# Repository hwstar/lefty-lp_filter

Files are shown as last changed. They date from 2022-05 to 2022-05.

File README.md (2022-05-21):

# Lefty-lp_filter
Lefty 8 Band Low Pass filter board

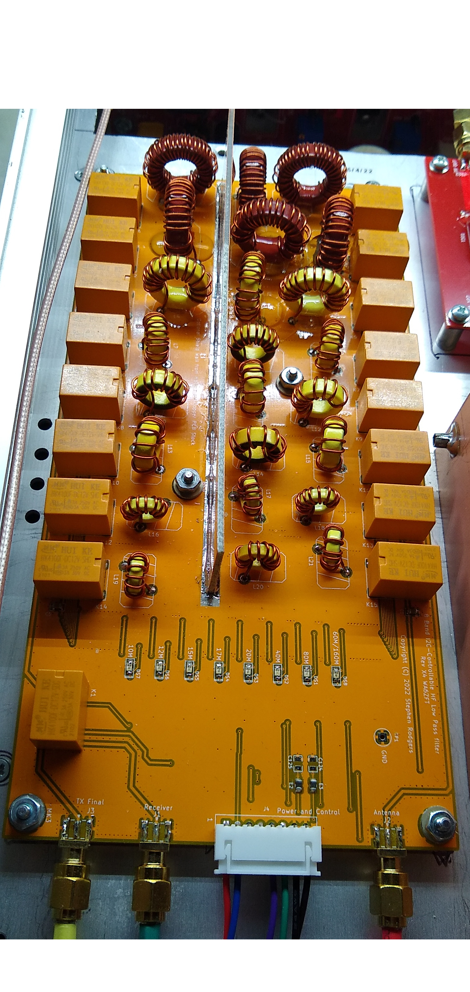
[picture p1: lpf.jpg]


This is an 8 band low pass filter board for the Lefty Transceiver.

The schematic capture and pwb layout was originally done in KiCAD 5 and migrated to KiCAD 6.

The filters are individually selectable via an I2C port expander.

The filter topology used in the design is:

"Second-Harmonic Optimized Low Pass Filters" by Ed Wetherhold, W3NQN
https://www.arrl.org/files/file/Technology/tis/info/pdf/9902044.pdf

The pdf schematic file is: lp_filter_8_bands.pdf

The BOM file is: lp_filter_8_bands_BOM.csv

The gerber files are in the directory LPF_X4_FAB.

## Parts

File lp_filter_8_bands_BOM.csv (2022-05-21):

Item | Part Number | Qty | Reference(s) | Title/Description | Value on Schematic | Manufacturer | Manufacturer Part Number
1 | 800003-104 | 23 | C1,C4-C8,C107-C123 | CAP,0805,0.1u,25V,X5R | 0.1u | Open Market | N/A
2 | 800232-470 | 3 | C10,C36,C94 | CAP,0805,C0G,47PF,250V | 47p | Open Market | N/A
3 | 800232-222 | 2 | C98,C101 | CAP,0805,C0G,2200PF,250V | 2200p | Open Market | N/A
4 | 800232-331 | 11 | C24,C27,C28,C30,C31,C33,C40,C43,C93,C99,C102 | CAP,0805,C0G,330PF,250V | 330p | Open Market | N/A
5 | 800232-152 | 2 | C95,C104 | CAP,0805,C0G,1500PF,250V | 1500p | Open Market | N/A
6 | 800232-151 | 7 | C9,C53,C56,C63,C72,C96,C105 | CAP,0805,C0G,150PF,250V | 150p | Open Market | N/A
7 | 800232-471 | 2 | C11,C20 | CAP,0805,C0G,470PF,250V | 470p | Open Market | N/A
8 | 800232-391 | 2 | C12,C21 | CAP,0805,C0G,390PF,250V | 390p | Open Market | N/A
9 | 800239-101 | 2 | C124,C125 | CAP,0805,C0G/NPO,100PF,50V | 100p | Open Market | N/A
10 | 800232-122 | 2 | C14,C17 | CAP,0805,C0G,1200PF,250V | 1200p | Open Market | N/A
11 | 800232-101 | 9 | C15,C18,C23,C25,C34,C54,C57,C85,C91 | CAP,0805,C0G,100PF,250V | 100p | Open Market | N/A
12 | 800003-106 | 2 | C2,C3 | CAP,0805,10u,25V,X5R | 10u | Open Market | N/A
13 | 800232-221 | 4 | C37,C46,C66,C69 | CAP,0805,C0G,220PF,250V | 220p | Open Market | N/A
14 | 800232-390 | 1 | C49 | CAP,0805,C0G,39PF,250V | 39p | Open Market | N/A
15 | 800232-820 | 8 | C50,C51,C59,C60,C87-C90 | CAP,0805,C0G,82PF,250V | 82p | Open Market | N/A
16 | 800232-330 | 1 | C62 | CAP,0805,C0G,33PF,250V | 33p | Open Market | N/A
17 | 800232-270 | 2 | C75,C84 | CAP,0805,C0G,27PF,250V | 27p | Open Market | N/A
18 | 800232-121 | 2 | C76,C82 | CAP,0805,C0G,120PF,250V | 120p | Open Market | N/A
19 | 800232-181 | 2 | C78,C80 | CAP,0805,C0G,180PF,250V | 180p | Open Market | N/A
20 | 800127-101 | 9 | CR1-CR9 | DIODE,SCHOTTKY,SGL,SOT-23 | BAT54 | Diodes Inc. | BAT54-7-F
21 | 800113-102 | 8 | DS1-DS8 | LED,GREEN,0805 | GREEN | Open Market | N/A
22 | 800245-601 | 3 | E1-E3 | FERRITE,CHIP,0805,600 ohm,100MHz,500mA | FB0805 | Sunlord | GZ2012U601TF
23 | 800233-101 | 3 | J1-J3 | CONN,SOC,SMA,LAUNCH,0.062 PCB | CONN_SMA_LAUNCH | Kinghelm | KH-SMA-KE8-G
24 | 800114-108 | 1 | J4 | CONN,HDR,SHROUDED,8 CKT,5MM,XH SERIES | CONN8 | JST | B8B-XH-A
25 | 800231-101 | 17 | K1-K17 | RELAY,SPDT,12V,3A | HK4100F-DC12V-SHCG | HUIKE | HK4100F-DC12V-SHCG
26 | 800234-802 | 6 | L1-L3,L22-L24 | TOROID,POWDERED_IRON,T80-2 | 2.68uH | Open Market | T80-2
27 | 800234-506 | 15 | L7-L21 | TOROID,POWDERED_IRON,T50-6 | 0.67uH | Open Market | T50-6
28 | 800234-686 | 3 | L4-L6 | TOROID,POWDERED_IRON,T68-6 | 1.34uH | Open Market | T68-6
29 | 800110-101 | 8 | Q1-Q8 | XSTR,GP,NPN,40V,SOT23 | MMBT4401 | Fairchild Semiconductor | MMBT4401
30 | 800235-222 | 8 | R1,R3,R7,R9,R19,R21,R23,R25 | RES,0805,2.2K,1% | 2.2K | Open Market | N/A
31 | 800235-123 | 8 | R10-R17 | RES,0805,12K,1% | 12K | Open Market | N/A
32 | 800235-102 | 8 | R2,R4,R8,R18,R20,R22,R24,R26 | RES,0805,1.0K,1% | 1K | Open Market | N/A
33 | 800235-103 | 2 | R5,R6 | RES,0805,10K,1% | 10K | Open Market | N/A
34 | 800116-101 | 1 | TP1 | CONN,HDR,1CKT,0.1PITCH,BERGSTRIP | GND | Open Market | N/A
35 | 800237-101 | 1 | U1 | IC, I2C BUS EXPANDER, 8 BIT, TSSOP16 | PCA9554APW | NEXPERIA | PCA9554APW
36 | 800121-101 | 1 | VR1 | IC,VREG,3.3V,1A,SOT-223 | NCP1117ST33 | On Semiconductor | NCP1117ST33T3G
37 | XXXXXX-XXX | 38 | C100,C103,C106,C13,C16,C19,C22,C26,C29,C32,C35,C38,C39,C41,C42,C44,C45,C47,C48,C52,C55,C58,C61,C64,C65,C67,C68,C70,C71,C73,C74,C77,C79,C81,C83,C86,C92,C97 | DNI | DNI | DNI | DNI

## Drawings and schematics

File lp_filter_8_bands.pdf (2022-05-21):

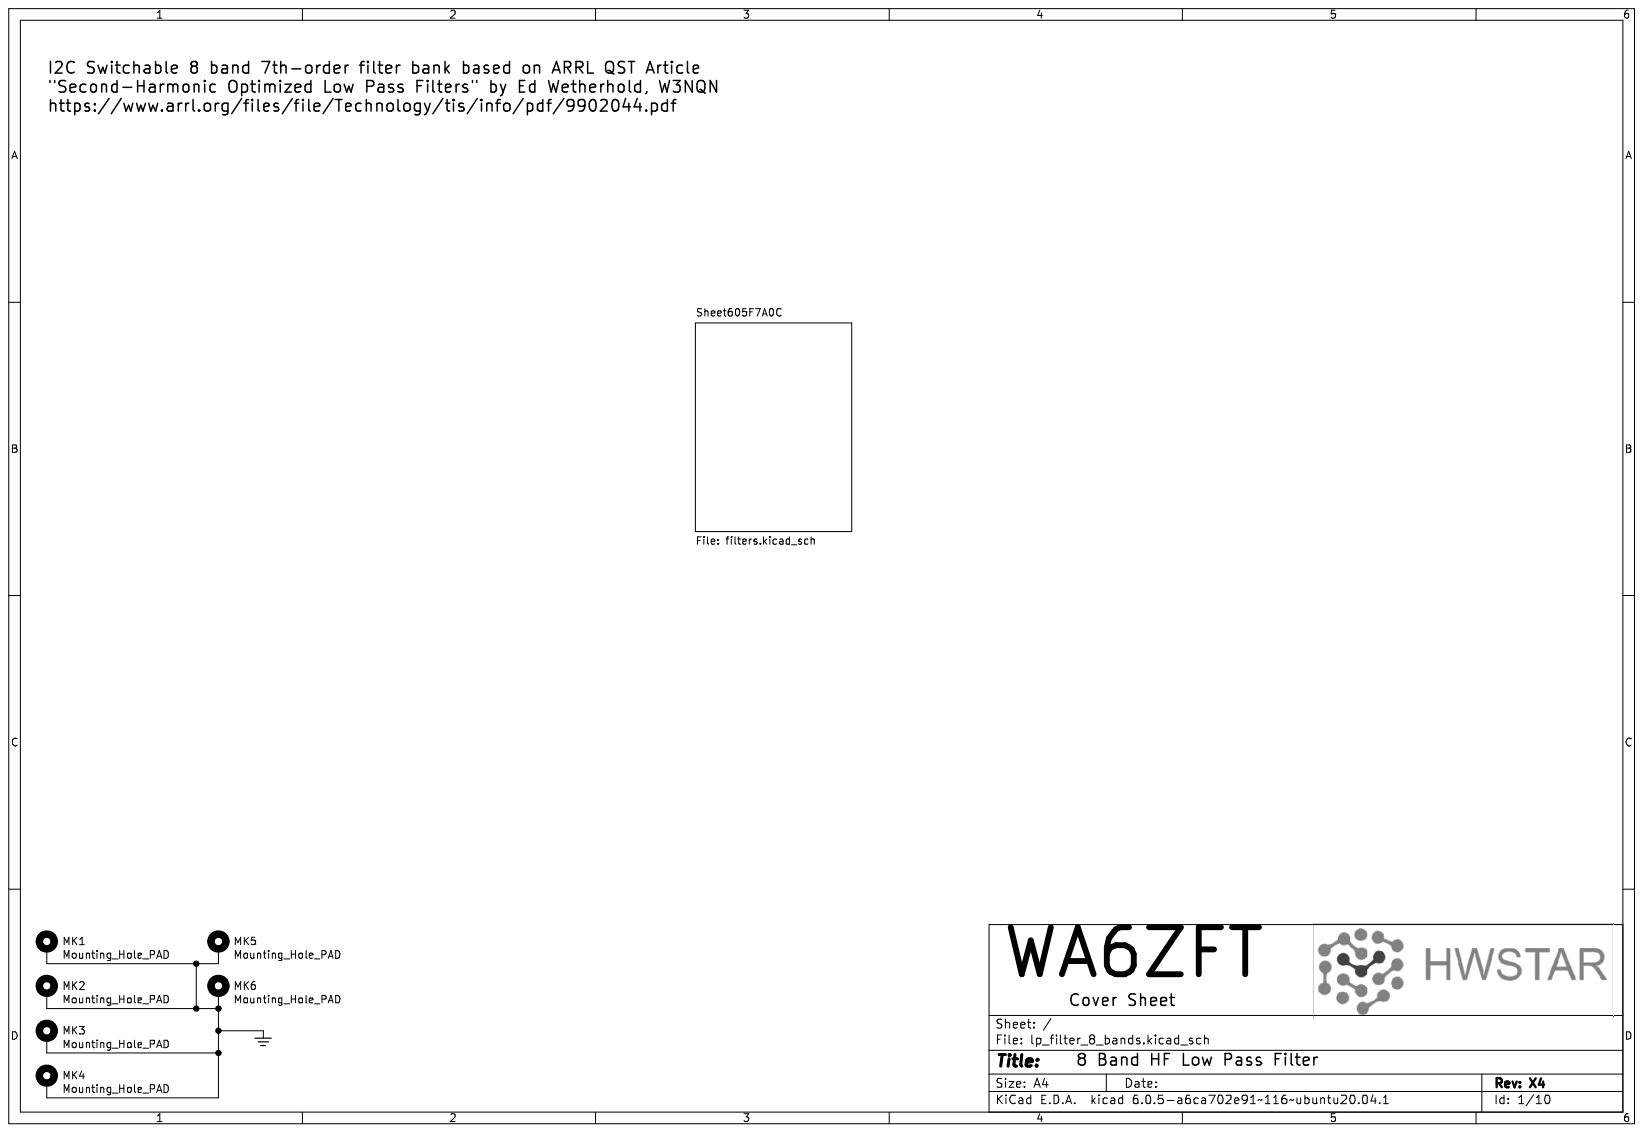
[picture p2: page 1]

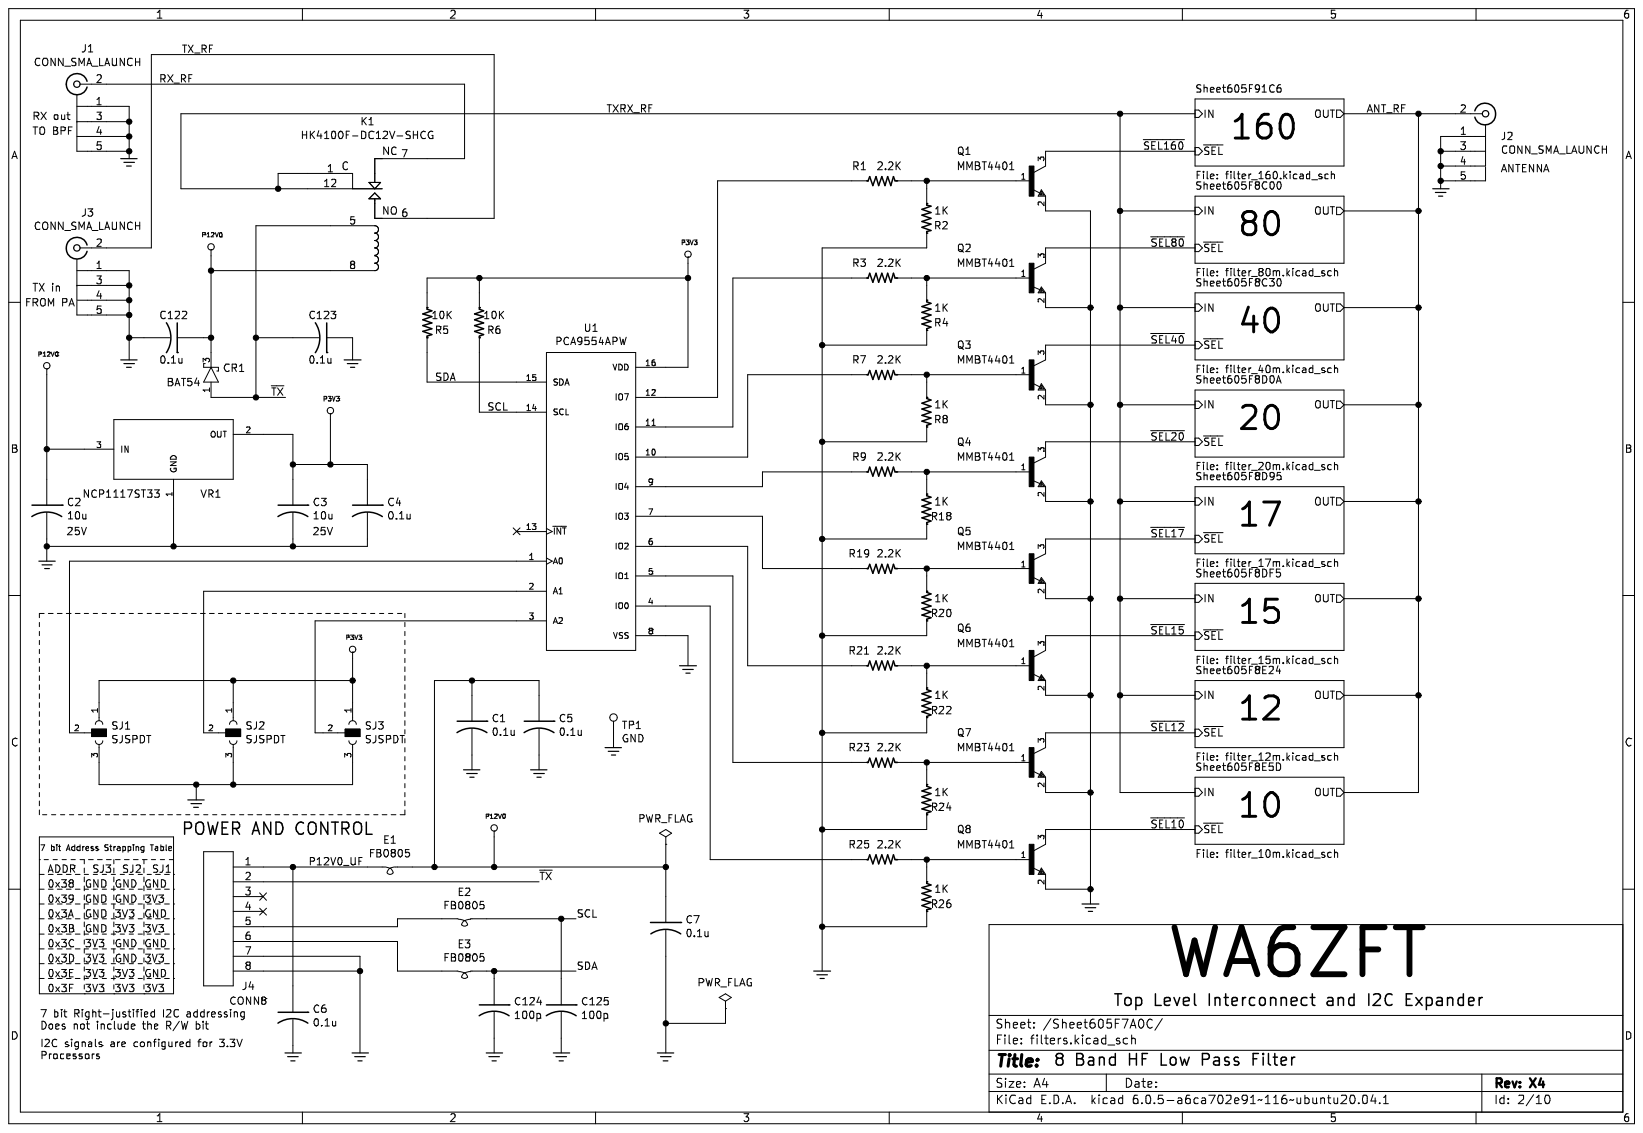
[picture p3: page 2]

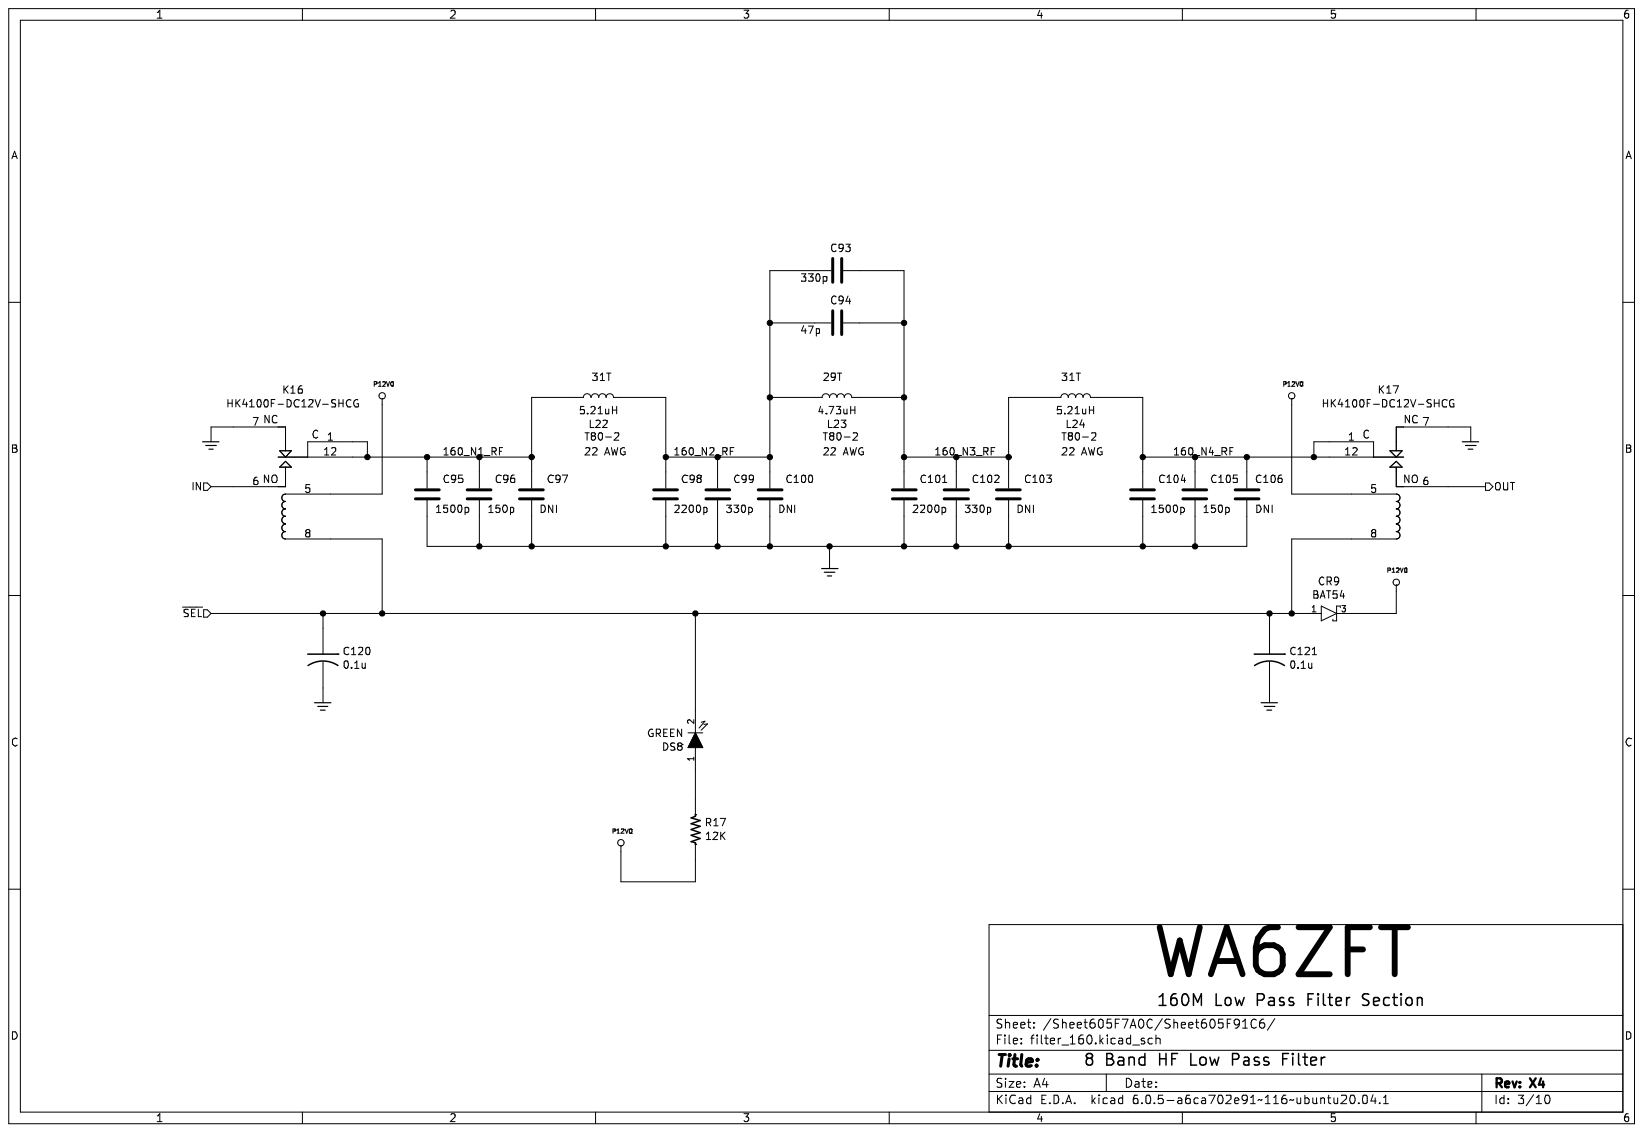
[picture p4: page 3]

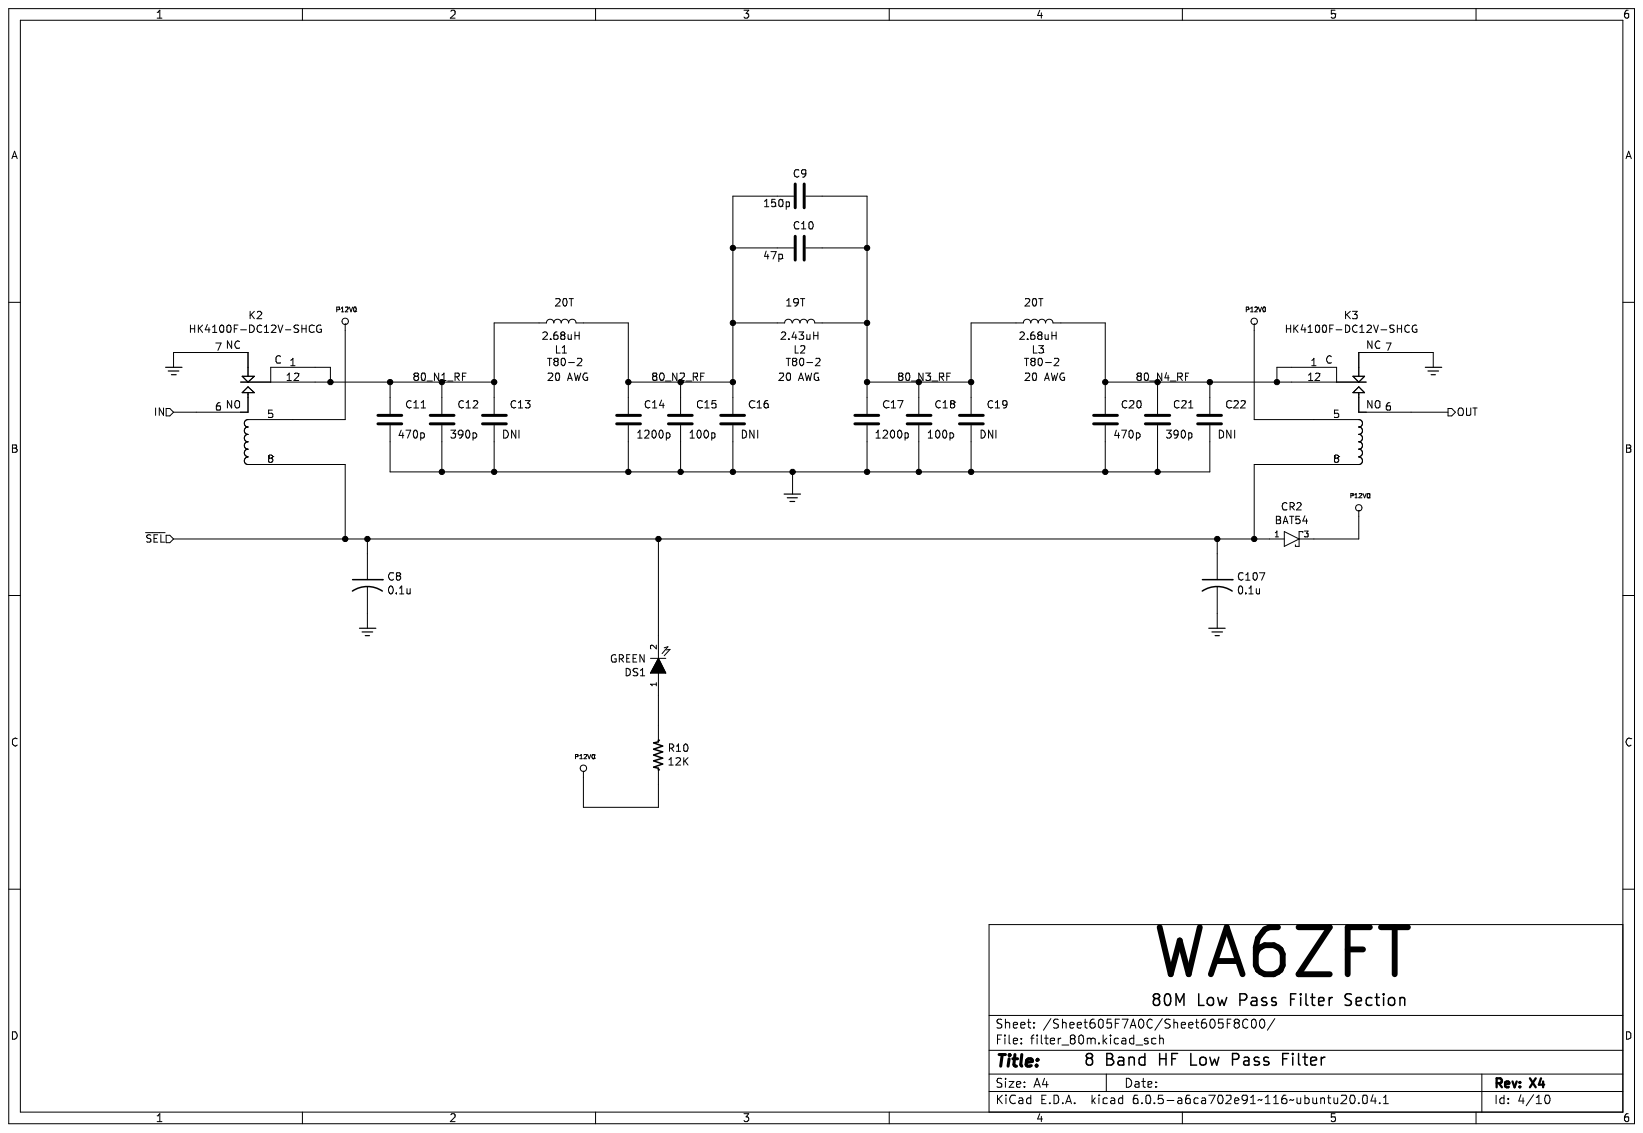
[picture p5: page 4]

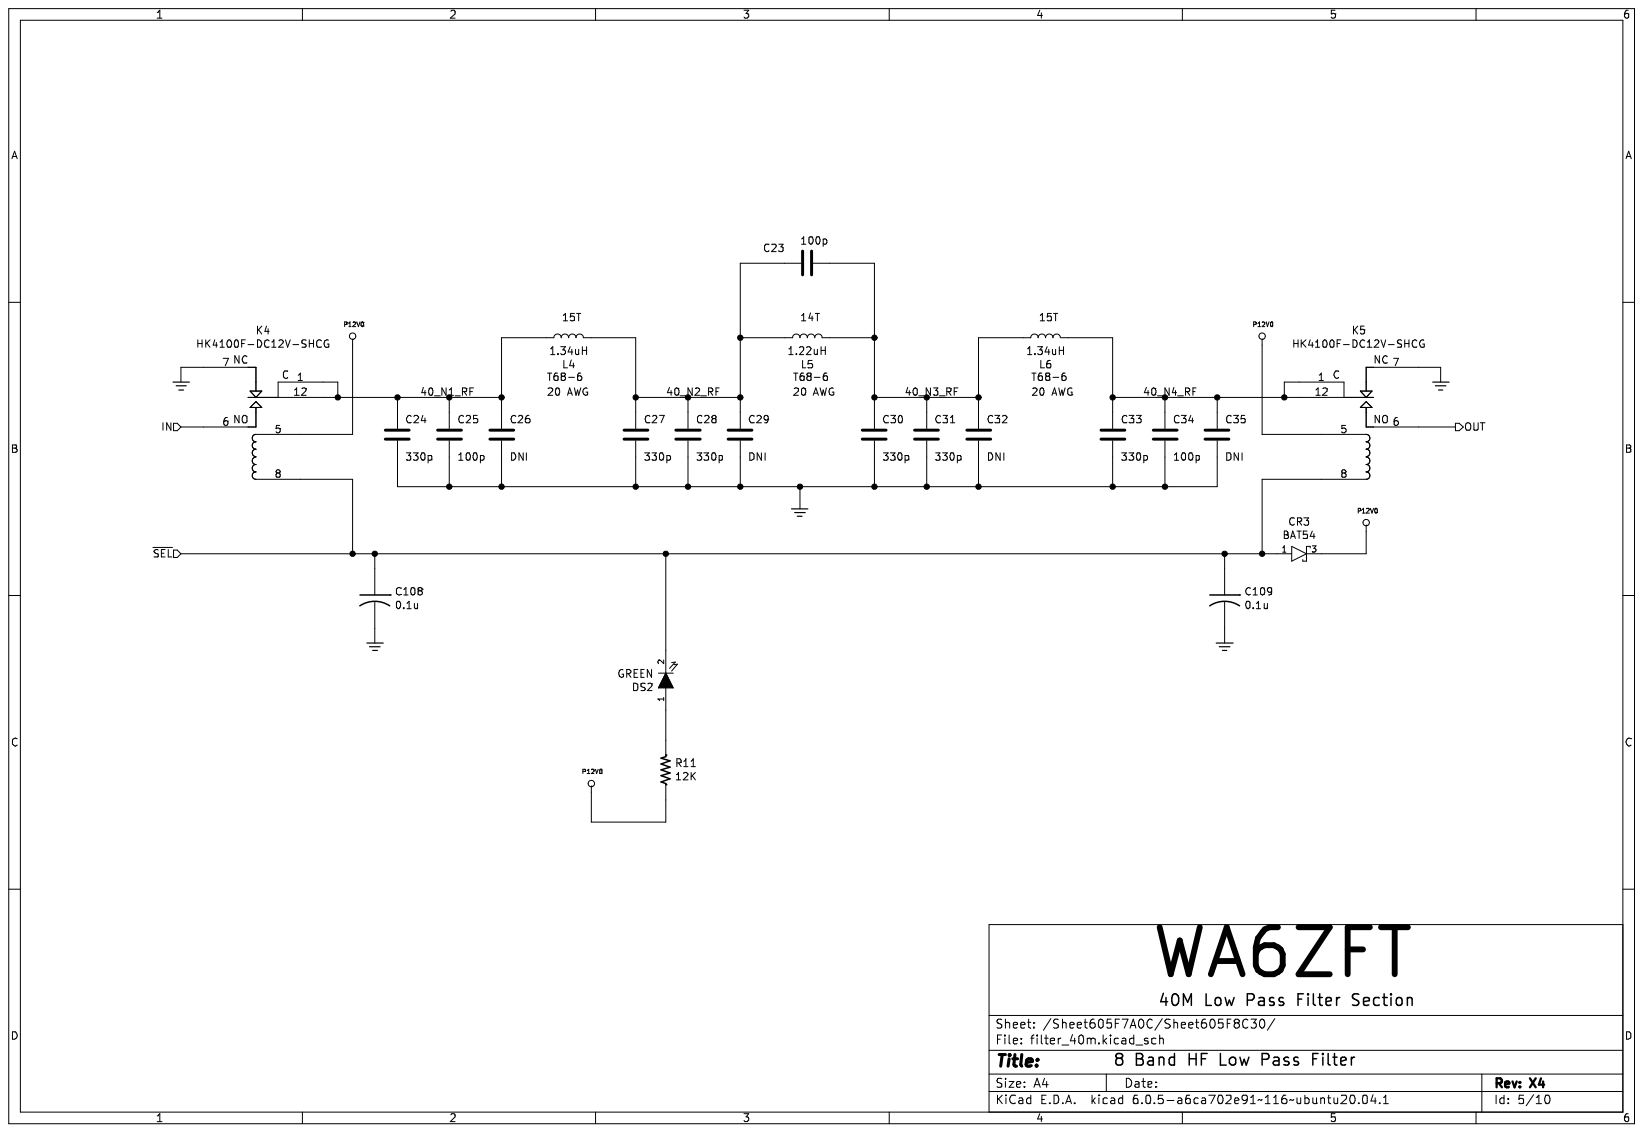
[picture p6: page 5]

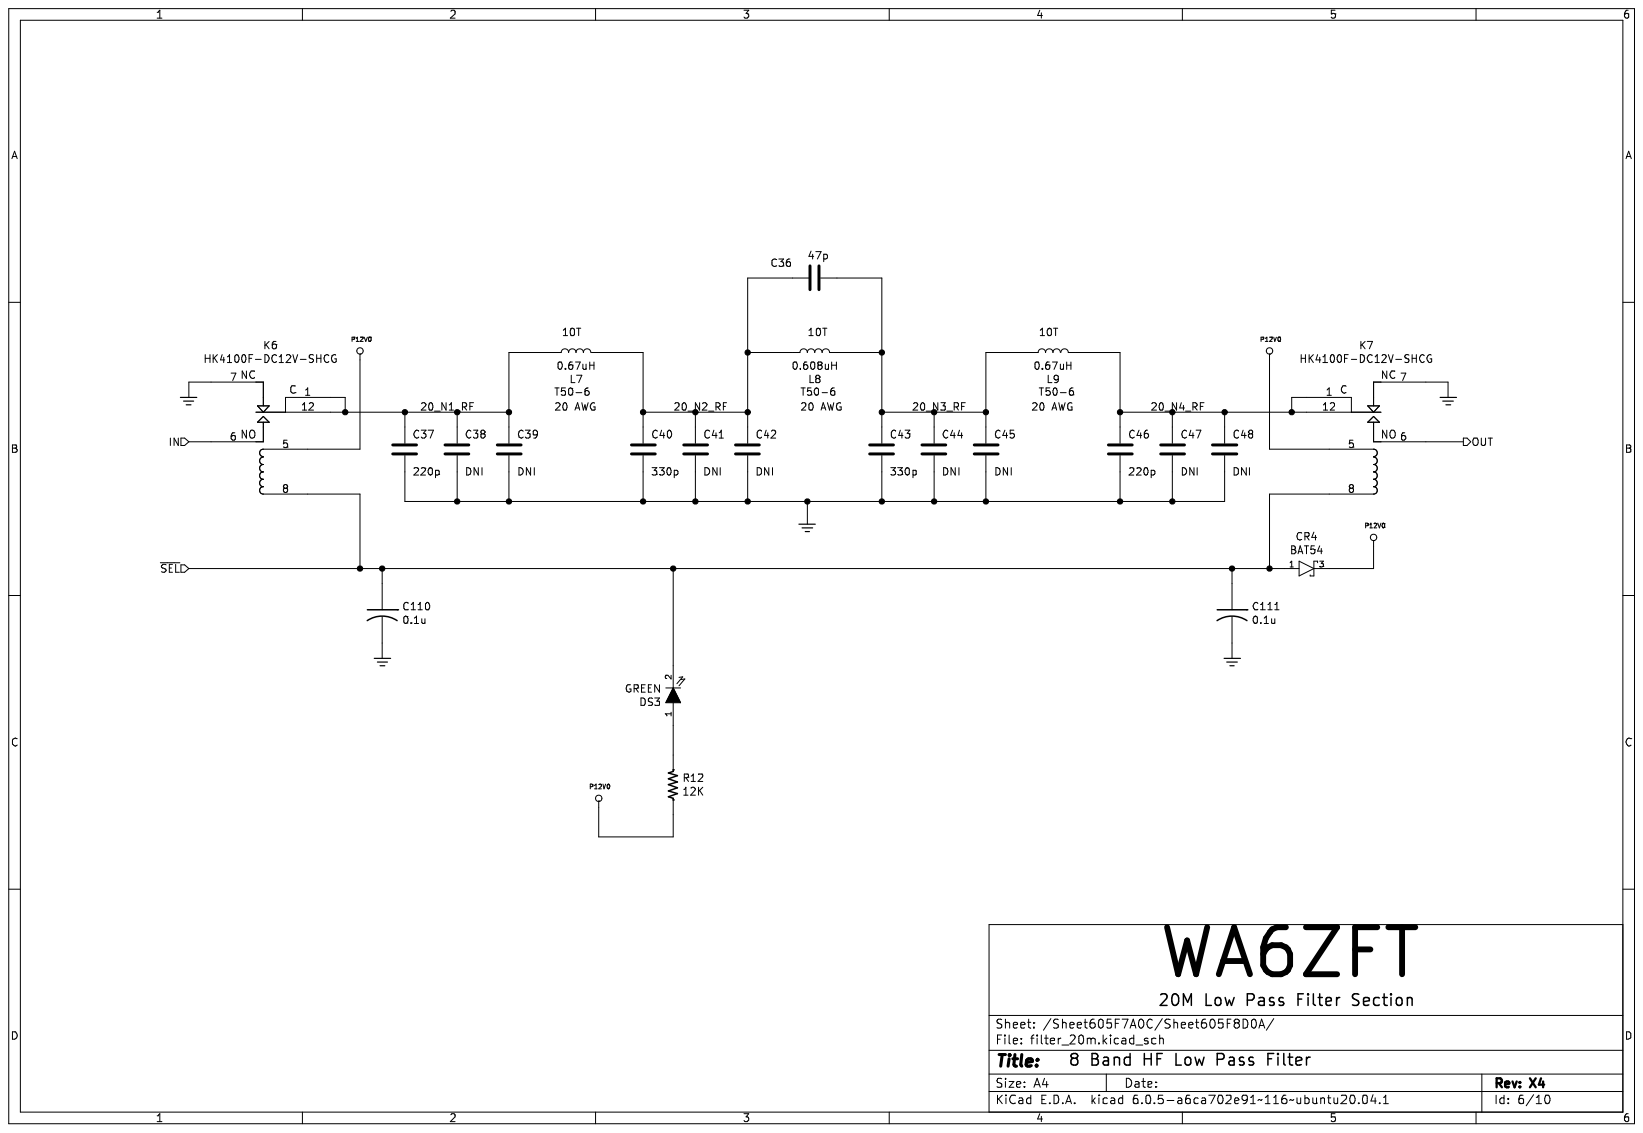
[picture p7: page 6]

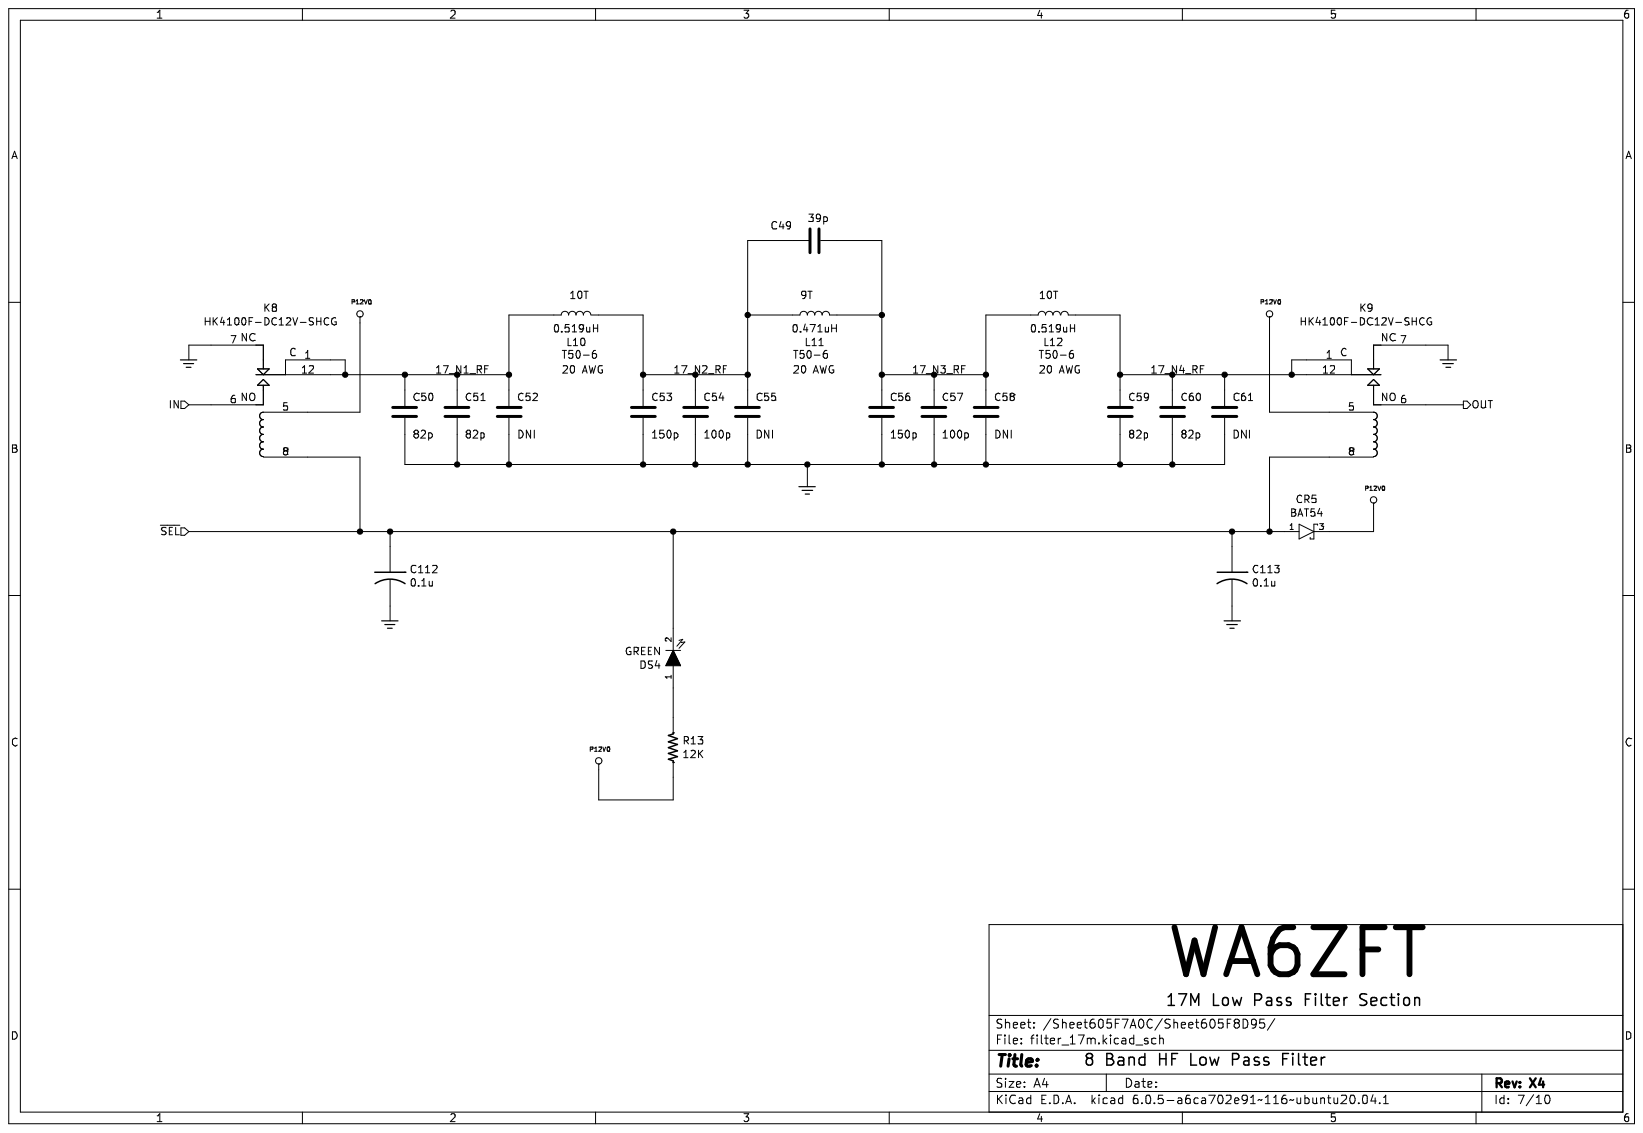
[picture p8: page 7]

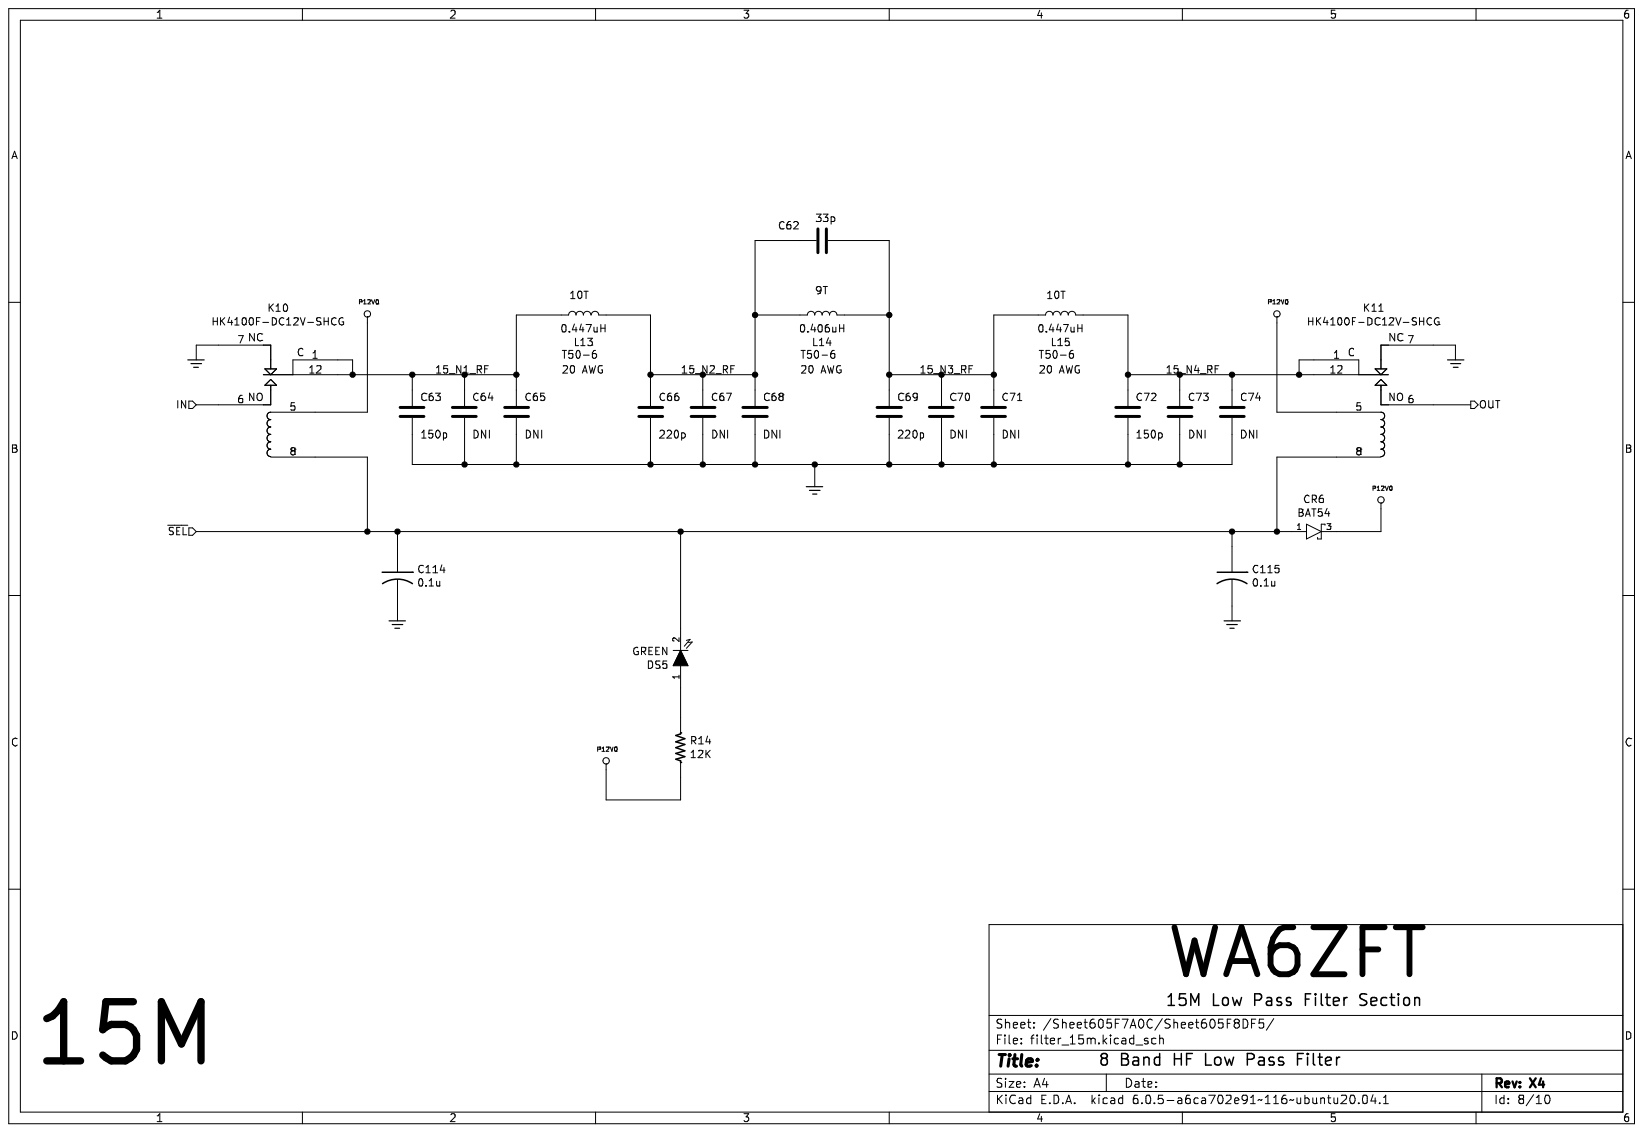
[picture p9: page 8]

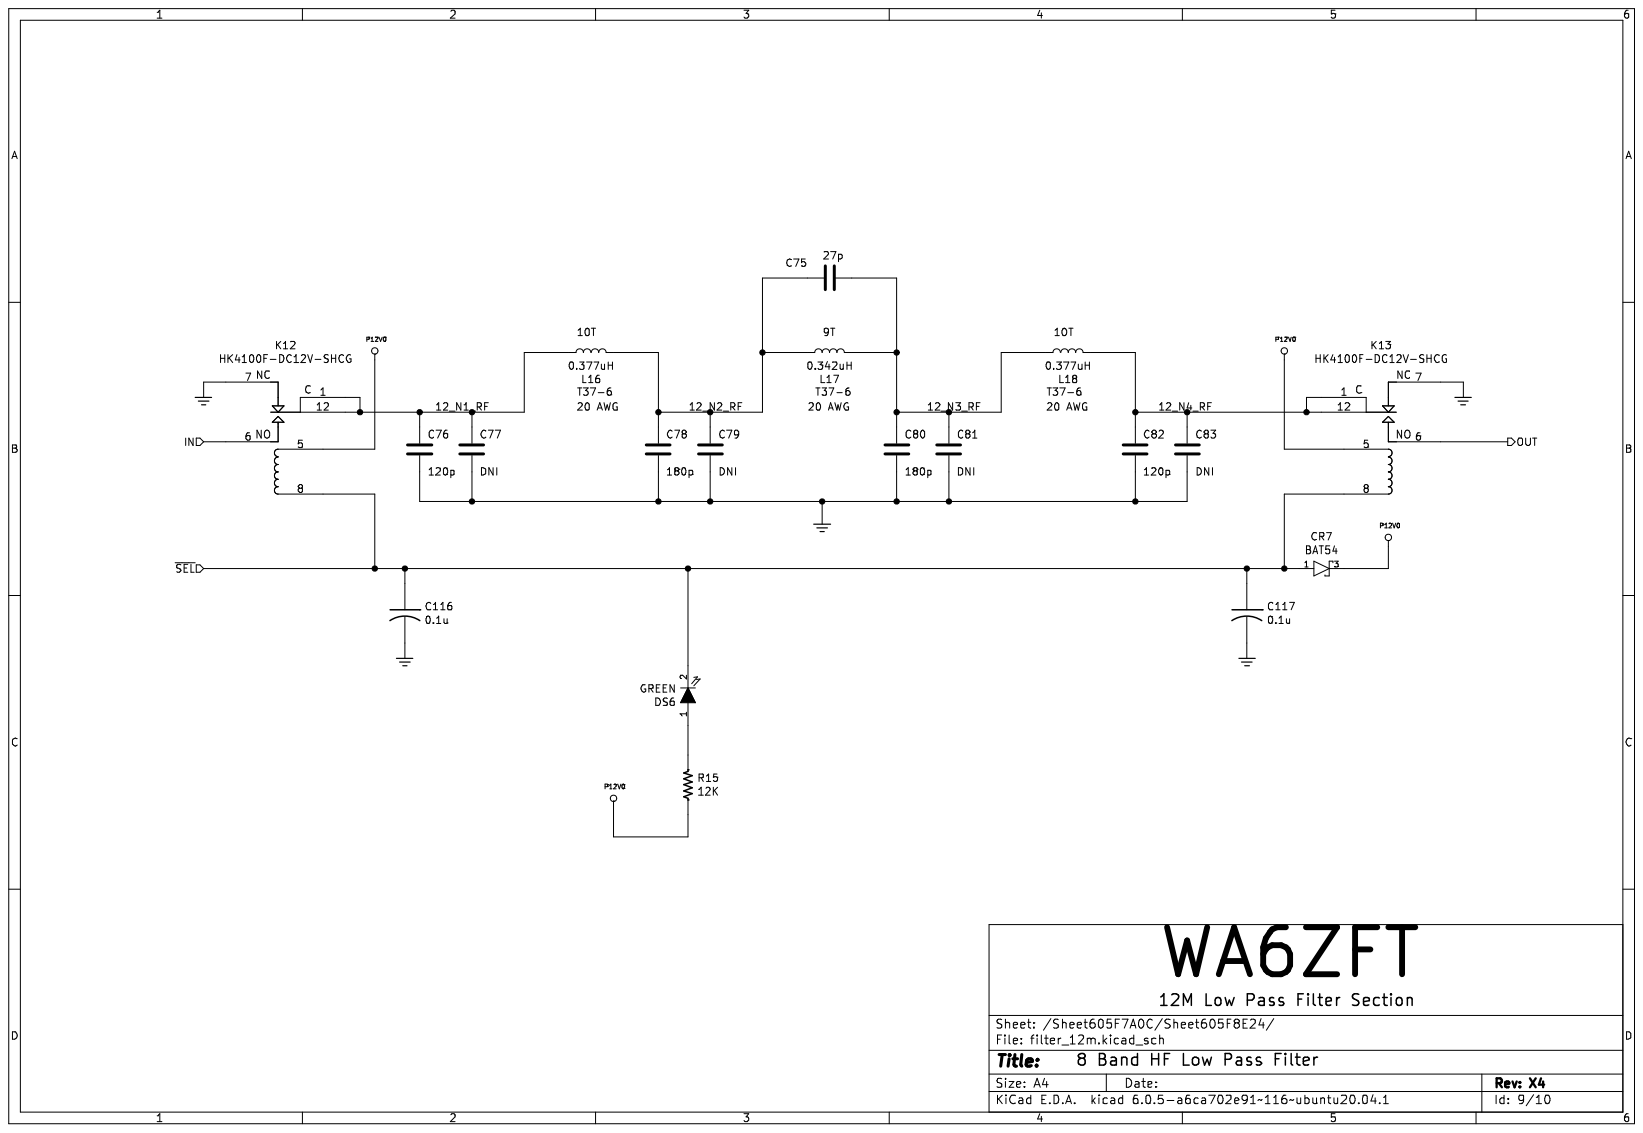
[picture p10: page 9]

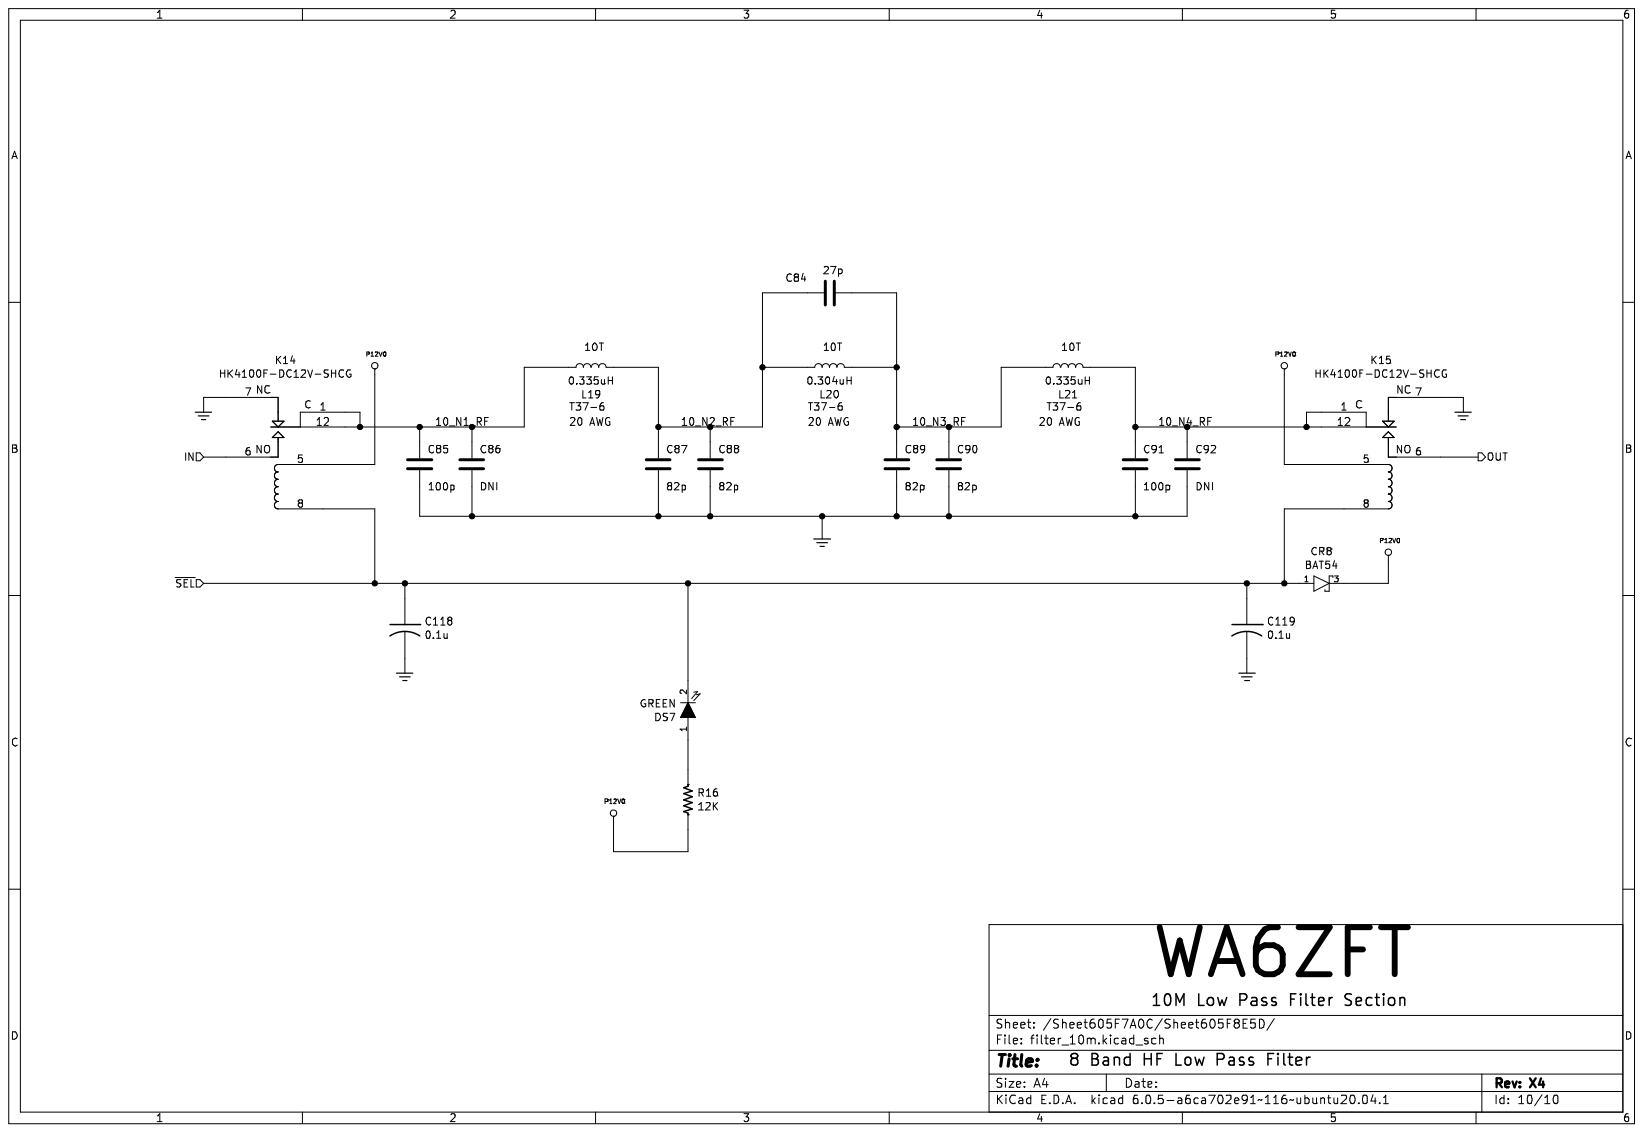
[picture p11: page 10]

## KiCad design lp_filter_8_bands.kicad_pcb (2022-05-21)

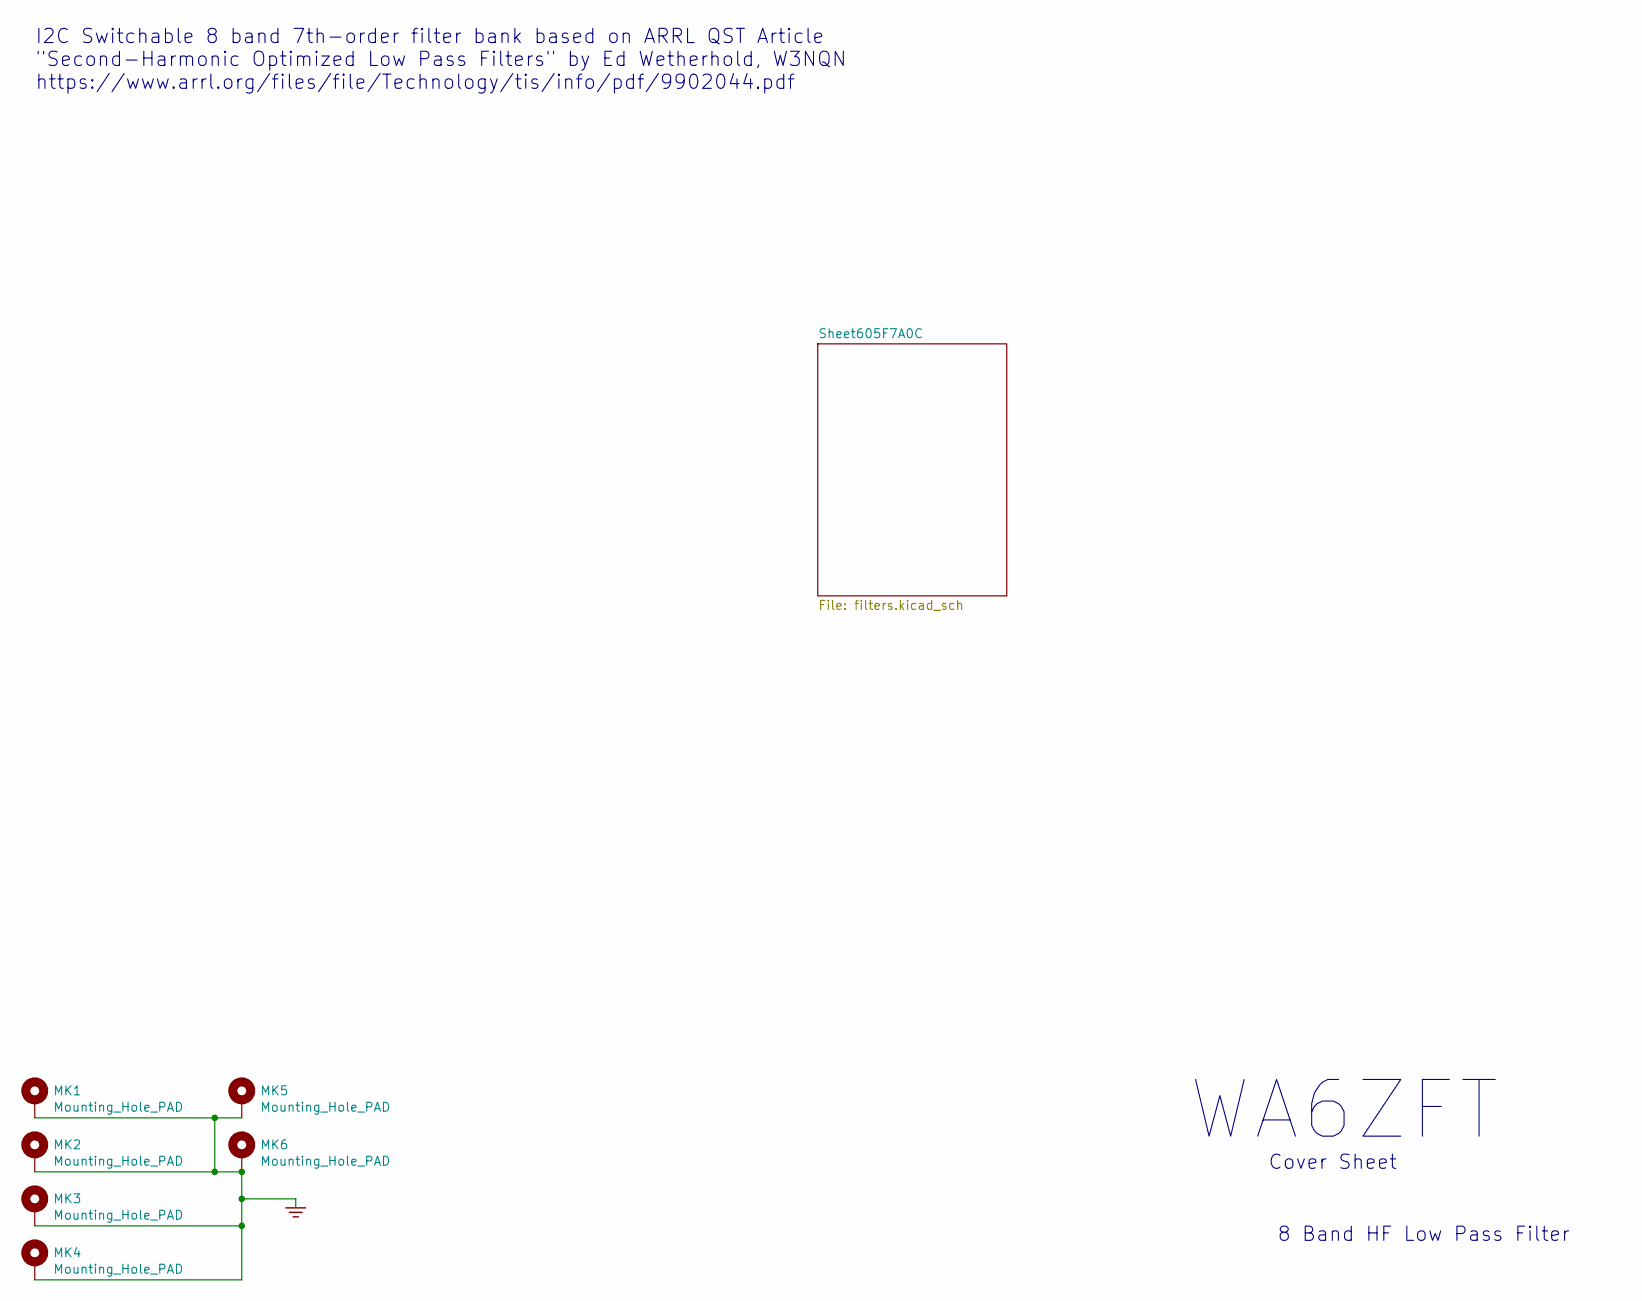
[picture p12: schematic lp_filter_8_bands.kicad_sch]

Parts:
MK1, MK2, MK3, MK4, MK5, MK6: Mounting_Hole_PAD; MountingHole_3.5mm_Pad_Via

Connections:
GND: MK1.1, MK2.1, MK3.1, MK4.1, MK5.1, MK6.1; also elsewhere on the board

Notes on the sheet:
WA6ZFT
Cover Sheet
I2C Switchable 8 band 7th-order filter bank based on ARRL QST Article "Second-Harmonic Optimized Low Pass Filters" by Ed Wetherhold, W3NQN https://www.arrl.org/files/file/Technology/tis/info/pdf/9902044.pdf
8 Band HF Low Pass Filter

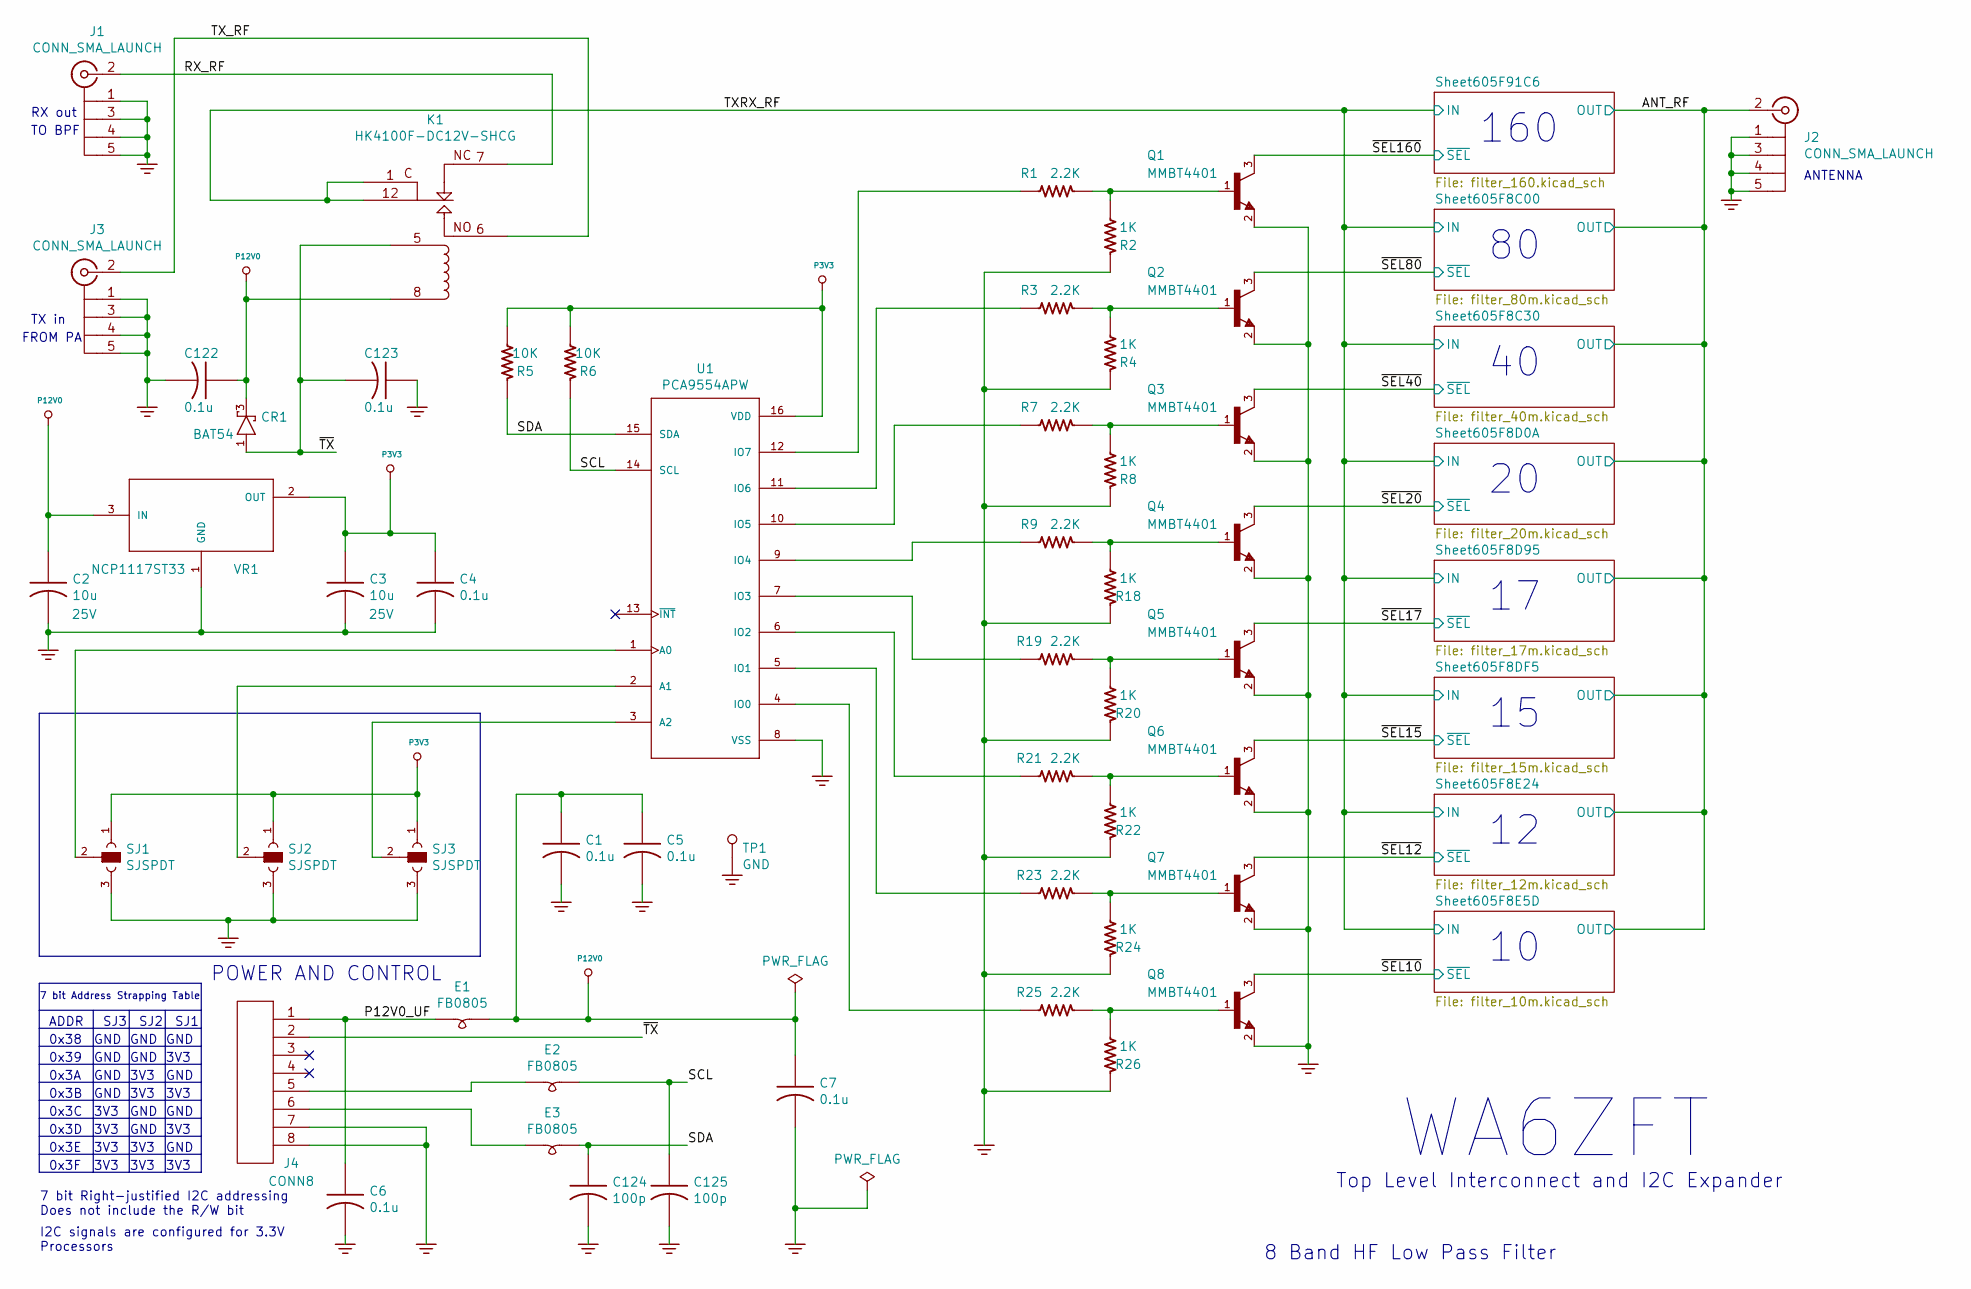
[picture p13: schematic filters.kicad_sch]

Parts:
C1, C4, C5, C6, C7, C122, C123: 0.1u; CC0805; PartNumber 800063-XXX
C2, C3: 10u; CC1206; Voltage 25V; PartNumber 800063-XXX
C124, C125: 100p; CC0805; PartNumber 800063-XXX
CR1: BAT54; SOT23-3-SAR-V2; PartNumber 800127-101
E1, E2, E3: FB0805; L_0805_2012Metric_Pad1.05x1.20mm_HandSolder; PartNumber 80000X-XXX
J1, J2, J3: CONN_SMA_LAUNCH; SMA_Launch_Kinghelm_KH-SMA-KE8-G; PartNumber 800233-101
J4: CONN8; JST_B8B_XH_A; PartNumber 800114-108
K1: HK4100F-DC12V-SHCG; RELAY_HK4100; PartNumber 800231-101
Q1, Q2, Q3, Q4, Q5, Q6, Q7, Q8: MMBT4401; SOT23-3-SAR-V2; PartNumber 800110-101
R1, R3, R7, R9, R19, R21, R23, R25: 2.2K; RC0805; PartNumber 800XXX-XXX
R2, R4, R8, R18, R20, R22, R24, R26: 1K; RC0805; PartNumber 800XXX-XXX
R5, R6: 10K; RC0805; PartNumber 800XXX-XXX
SJ1, SJ2, SJ3: SJSPDT
TP1: GND; TESTPIN; PartNumber 800116-101
U1: PCA9554APW; TSSOP-16_4.4x5mm_P0.65mm; PartNumber 800237-101
VR1: NCP1117ST33; SOT-223-3_TabPin2; PartNumber 800121-101

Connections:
/Sheet605F7A0C/ANT_RF: J2.2; also elsewhere on the board
/Sheet605F7A0C/P12V0_UF: C6.1, E1.1, J4.1
/Sheet605F7A0C/RX_RF: J1.2, K1.7
/Sheet605F7A0C/SCL: C125.1, E2.2, R6.1, U1.14 (SCL)
/Sheet605F7A0C/SDA: C124.1, E3.2, R5.1, U1.15 (SDA)
/Sheet605F7A0C/TXRX_RF: K1.1, K1.12; also elsewhere on the board
/Sheet605F7A0C/TX_RF: J3.2, K1.6
/Sheet605F7A0C/~SEL10: Q8.3 (C); also elsewhere on the board
/Sheet605F7A0C/~SEL12: Q7.3 (C); also elsewhere on the board
/Sheet605F7A0C/~SEL15: Q6.3 (C); also elsewhere on the board
/Sheet605F7A0C/~SEL17: Q5.3 (C); also elsewhere on the board
/Sheet605F7A0C/~SEL20: Q4.3 (C); also elsewhere on the board
/Sheet605F7A0C/~SEL40: Q3.3 (C); also elsewhere on the board
/Sheet605F7A0C/~SEL80: Q2.3 (C); also elsewhere on the board
/Sheet605F7A0C/~SEL160: Q1.3 (C); also elsewhere on the board
/Sheet605F7A0C/~TX: C123.2, CR1.1 (A), J4.2, K1.5
GND: C1.2, C2.2, C3.2, C4.2, C5.2, C6.2, C7.2, C122.2, C123.1, C124.2, C125.2, J1.1, J1.3, J1.4, J1.5, J2.1, J2.3, J2.4, J2.5, J3.1, J3.3, J3.4, J3.5, J4.7, J4.8, Q1.2 (E), Q2.2 (E), Q3.2 (E), Q4.2 (E), Q5.2 (E), Q6.2 (E), Q7.2 (E), Q8.2 (E), R2.1, R4.1, R8.1, R18.1, R20.1, R22.1, R24.1, R26.1, SJ1.3, SJ2.3, SJ3.3, TP1.1 (TP), U1.8 (VSS), VR1.1 (GND); also elsewhere on the board
unnamed: E2.1, J4.5
unnamed: E3.1, J4.6
unnamed: Q1.1 (B), R1.1, R2.2
unnamed: Q2.1 (B), R3.1, R4.2
unnamed: Q3.1 (B), R7.1, R8.2
unnamed: Q4.1 (B), R9.1, R18.2
unnamed: Q5.1 (B), R19.1, R20.2
unnamed: Q6.1 (B), R21.1, R22.2
unnamed: Q7.1 (B), R23.1, R24.2
unnamed: Q8.1 (B), R25.1, R26.2
unnamed: R1.2, U1.12 (IO7)
unnamed: R3.2, U1.11 (IO6)
unnamed: R7.2, U1.10 (IO5)
unnamed: R9.2, U1.9 (IO4)
unnamed: R19.2, U1.7 (IO3)
unnamed: R21.2, U1.6 (IO2)
unnamed: R23.2, U1.5 (IO1)
unnamed: R25.2, U1.4 (IO0)
unnamed: SJ1.2, U1.1 (A0)
unnamed: SJ2.2, U1.2 (A1)
unnamed: SJ3.2, U1.3 (A2)
P3V3: C3.1, C4.1, R5.2, R6.2, SJ1.1, SJ2.1, SJ3.1, U1.16 (VDD), VR1.2 (OUT)
P12V0: C1.1, C2.1, C5.1, C7.1, C122.1, CR1.3 (C), E1.2, K1.8, VR1.3 (IN); also elsewhere on the board

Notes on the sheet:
GND
SJ2
3V3
0x3A
0x3E
0x3B
0x39
0x3D
ADDR
160
8 Band HF Low Pass Filter
7 bit Address Strapping Table
TX in
SJ3
I2C signals are configured for 3.3V Processors
Top Level Interconnect and I2C Expander
RX out
GND
7 bit Right-justified I2C addressing Does not include the R/W bit
0x3F
WA6ZFT
SJ1
0x38
FROM PA
POWER AND CONTROL
TO BPF
0x3C
ANTENNA

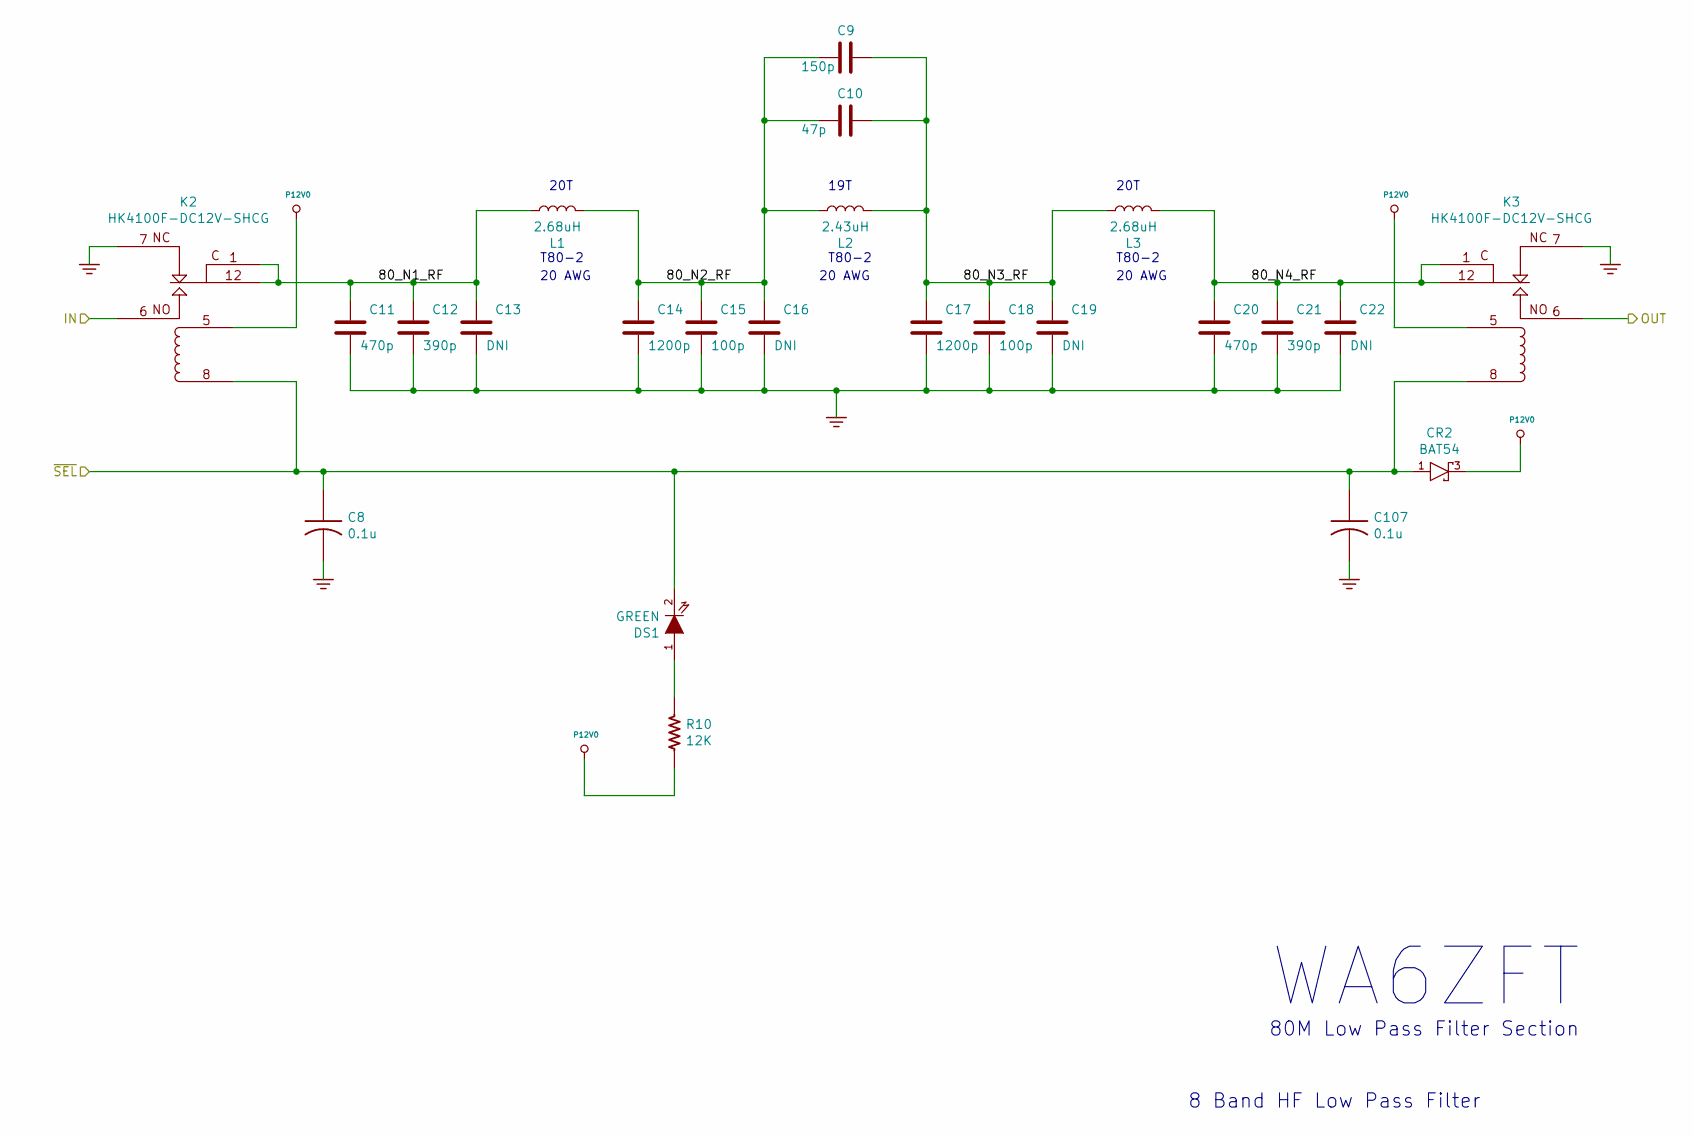
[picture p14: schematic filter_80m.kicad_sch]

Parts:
C8, C107: 0.1u; CC0805; PartNumber 800063-XXX
C9: 150p; CC0805; PartNumber 800232-151
C10: 47p; CC0805; PartNumber 800232-470
C11, C20: 470p; CC0805; PartNumber 800232-471
C12, C21: 390p; CC0805; PartNumber 800232-391
C13, C16, C19, C22: DNI; CC0805; PartNumber 800XXX-XXX
C14, C17: 1200p; CC0805; PartNumber 800232-122
C15, C18: 100p; CC0805; PartNumber 800232-101
CR2: BAT54; SOT23-3-SAR-V2; PartNumber 800127-101
DS1: GREEN; LED0805; PartNumber 800113-102
K2, K3: HK4100F-DC12V-SHCG; RELAY_HK4100; PartNumber 800231-101
L1, L3: 2.68uH; TOROID_T80_VERT; PartNumber 800234-802
L2: 2.43uH; TOROID_T80_VERT; PartNumber 800234-802
R10: 12K; RC0805; PartNumber 800XXX-XXX

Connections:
/Sheet605F7A0C/ANT_RF: K3.6; also elsewhere on the board
/Sheet605F7A0C/Sheet605F8C00/80_N1_RF: C11.1, C12.1, C13.1, K2.1, K2.12, L1.1
/Sheet605F7A0C/Sheet605F8C00/80_N2_RF: C9.2, C10.2, C14.1, C15.1, C16.1, L1.2, L2.1
/Sheet605F7A0C/Sheet605F8C00/80_N3_RF: C9.1, C10.1, C17.1, C18.1, C19.1, L2.2, L3.1
/Sheet605F7A0C/Sheet605F8C00/80_N4_RF: C20.1, C21.1, C22.1, K3.1, K3.12, L3.2
/Sheet605F7A0C/TXRX_RF: K2.6; also elsewhere on the board
/Sheet605F7A0C/~SEL80: C8.1, C107.1, CR2.1 (A), DS1.2 (K), K2.8, K3.8; also elsewhere on the board
GND: C8.2, C11.2, C12.2, C13.2, C14.2, C15.2, C16.2, C17.2, C18.2, C19.2, C20.2, C21.2, C22.2, C107.2, K2.7, K3.7; also elsewhere on the board
unnamed: DS1.1 (A), R10.1
P12V0: CR2.3 (C), K2.5, K3.5, R10.2; also elsewhere on the board

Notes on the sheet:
20 AWG
20T
8 Band HF Low Pass Filter
T80-2
19T
80M Low Pass Filter Section
WA6ZFT

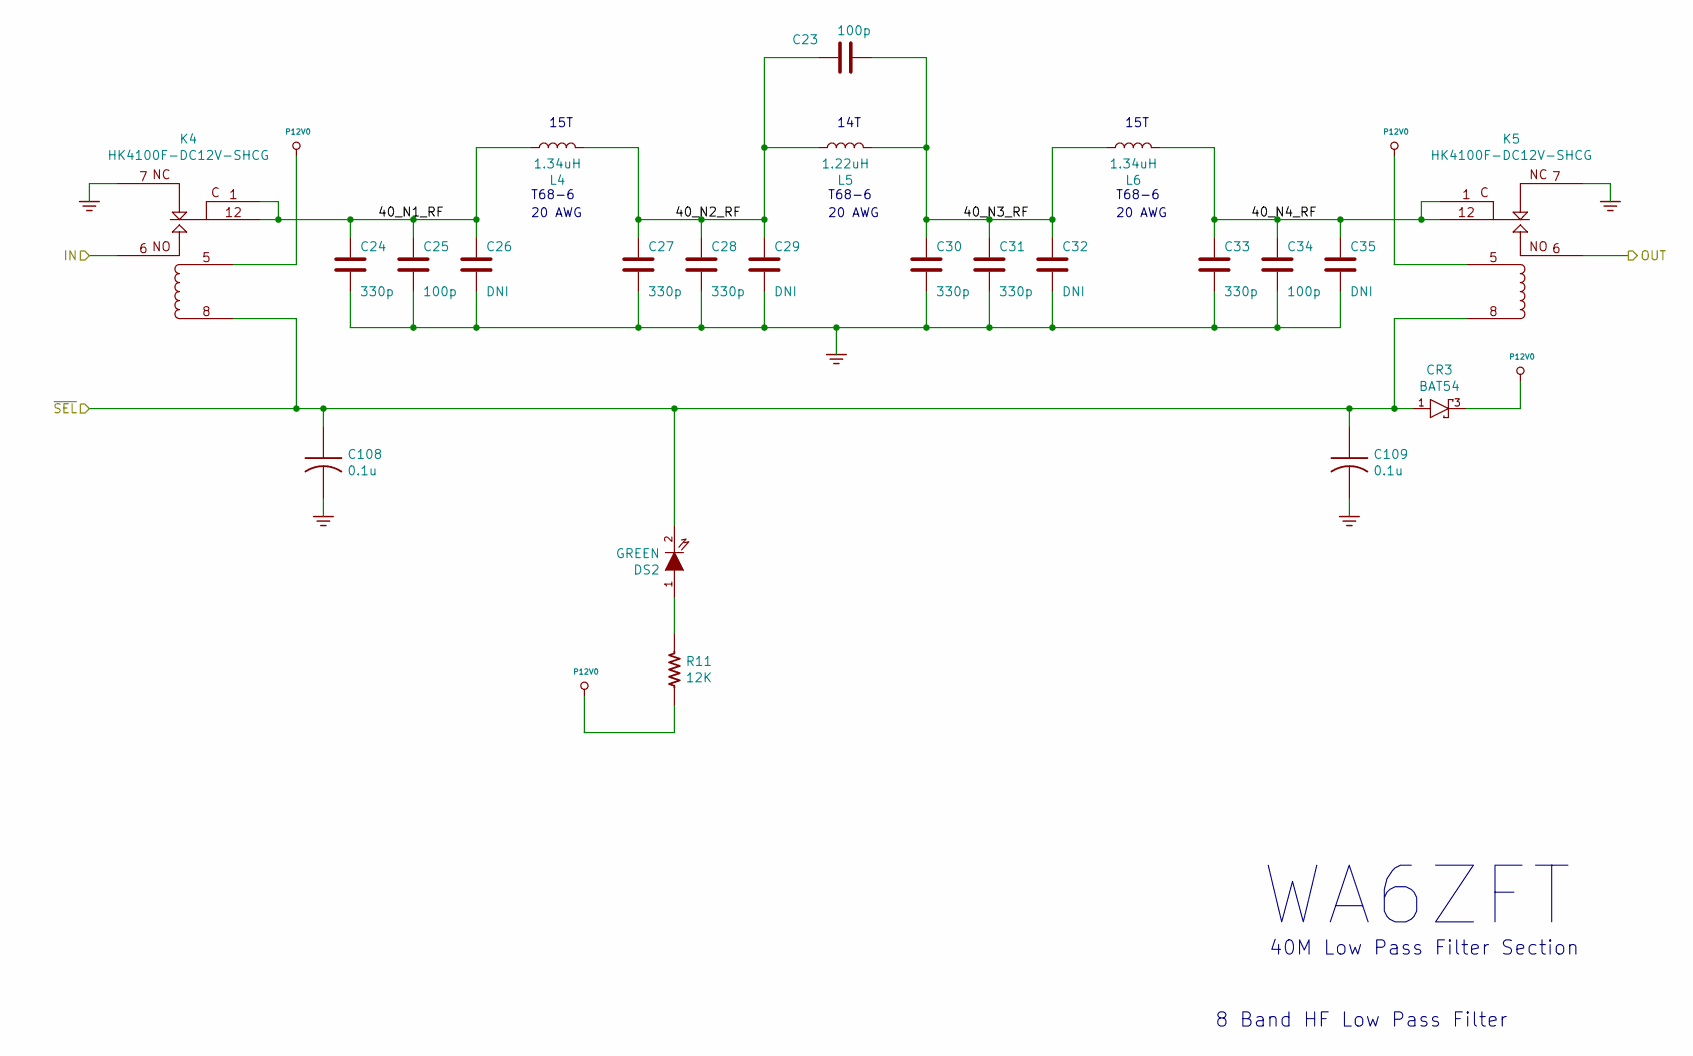
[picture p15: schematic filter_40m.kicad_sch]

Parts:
C23, C25, C34: 100p; CC0805; PartNumber 800232-101
C24, C27, C28, C30, C31, C33: 330p; CC0805; PartNumber 800232-331
C26, C29, C32, C35: DNI; CC0805; PartNumber 800XXX-XXX
C108, C109: 0.1u; CC0805; PartNumber 800063-XXX
CR3: BAT54; SOT23-3-SAR-V2; PartNumber 800127-101
DS2: GREEN; LED0805; PartNumber 800113-102
K4, K5: HK4100F-DC12V-SHCG; RELAY_HK4100; PartNumber 800231-101
L4, L6: 1.34uH; TOROID_T68_VERT; PartNumber 800234-686
L5: 1.22uH; TOROID_T68_VERT; PartNumber 800234-686
R11: 12K; RC0805; PartNumber 800XXX-XXX

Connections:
/Sheet605F7A0C/ANT_RF: K5.6; also elsewhere on the board
/Sheet605F7A0C/Sheet605F8C30/40_N1_RF: C24.1, C25.1, C26.1, K4.1, K4.12, L4.1
/Sheet605F7A0C/Sheet605F8C30/40_N2_RF: C23.2, C27.1, C28.1, C29.1, L4.2, L5.1
/Sheet605F7A0C/Sheet605F8C30/40_N3_RF: C23.1, C30.1, C31.1, C32.1, L5.2, L6.1
/Sheet605F7A0C/Sheet605F8C30/40_N4_RF: C33.1, C34.1, C35.1, K5.1, K5.12, L6.2
/Sheet605F7A0C/TXRX_RF: K4.6; also elsewhere on the board
/Sheet605F7A0C/~SEL40: C108.1, C109.1, CR3.1 (A), DS2.2 (K), K4.8, K5.8; also elsewhere on the board
GND: C24.2, C25.2, C26.2, C27.2, C28.2, C29.2, C30.2, C31.2, C32.2, C33.2, C34.2, C35.2, C108.2, C109.2, K4.7, K5.7; also elsewhere on the board
unnamed: DS2.1 (A), R11.1
P12V0: CR3.3 (C), K4.5, K5.5, R11.2; also elsewhere on the board

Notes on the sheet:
T68-6
40M Low Pass Filter Section
15T
8 Band HF Low Pass Filter
20 AWG
WA6ZFT
14T
15T

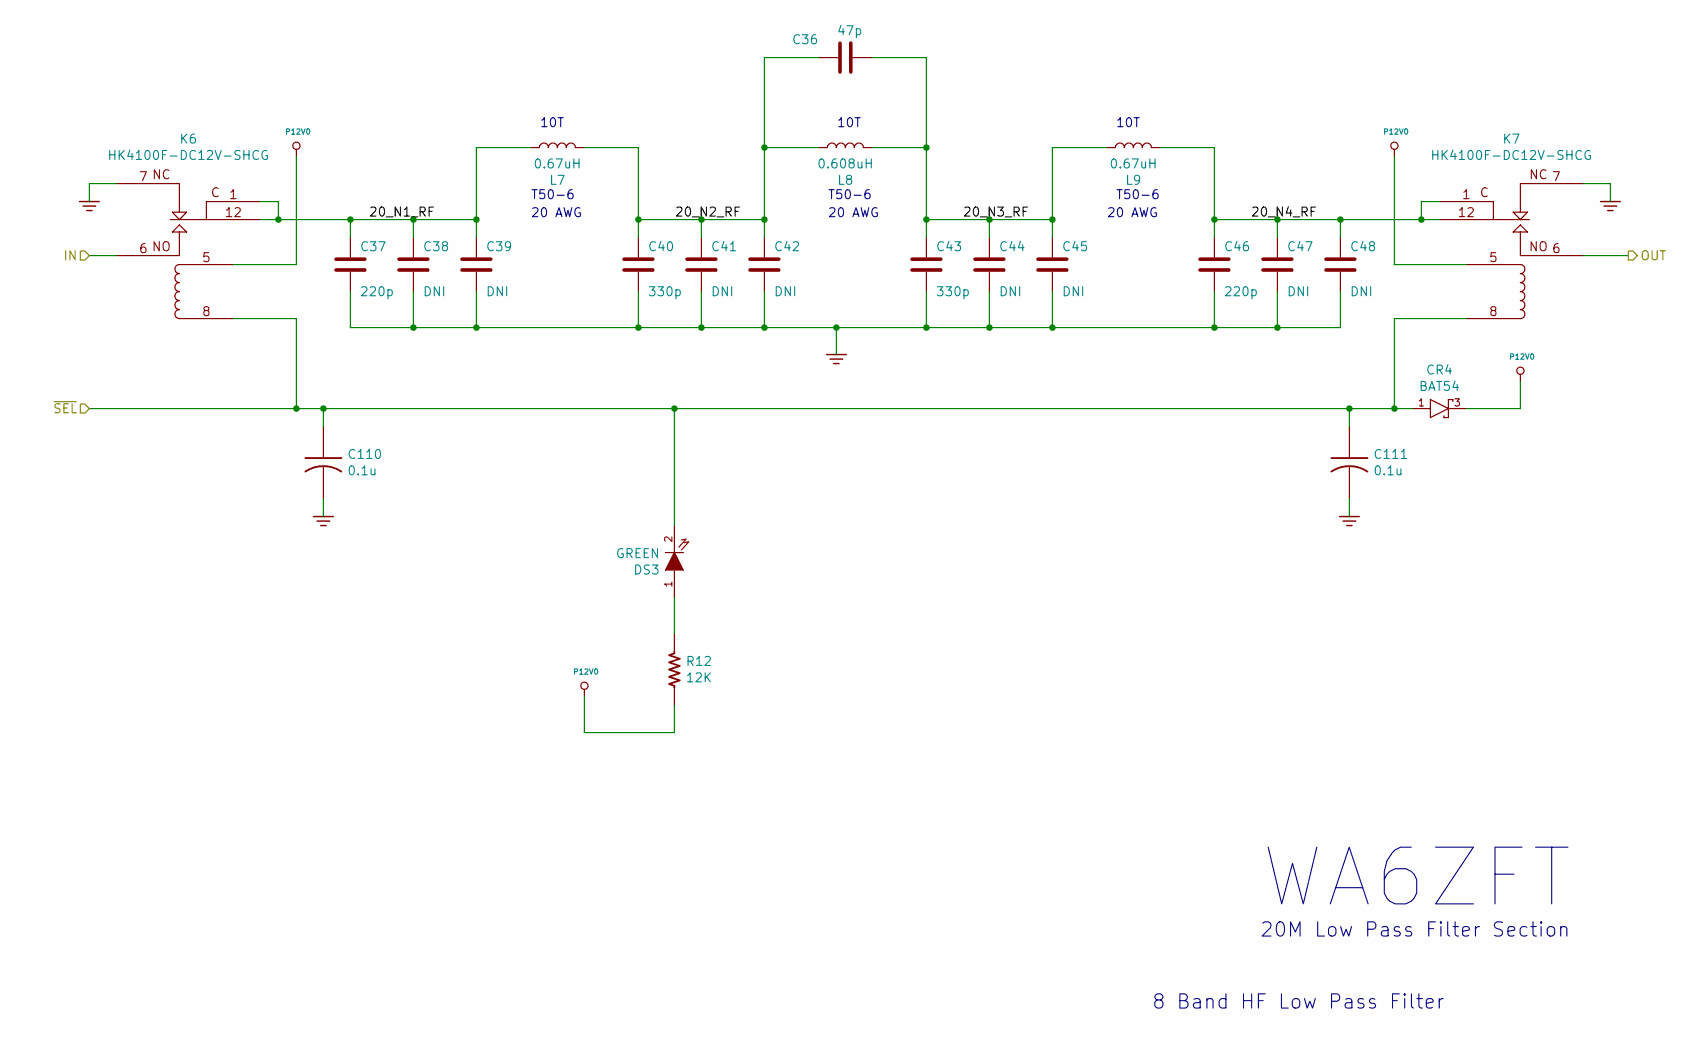
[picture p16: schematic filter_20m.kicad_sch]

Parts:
C36: 47p; CC0805; PartNumber 800232-470
C37, C46: 220p; CC0805; PartNumber 800232-221
C38, C39, C41, C42, C44, C45, C47, C48: DNI; CC0805; PartNumber 800XXX-XXX
C40, C43: 330p; CC0805; PartNumber 800232-331
C110, C111: 0.1u; CC0805; PartNumber 800063-XXX
CR4: BAT54; SOT23-3-SAR-V2; PartNumber 800127-101
DS3: GREEN; LED0805; PartNumber 800113-102
K6, K7: HK4100F-DC12V-SHCG; RELAY_HK4100; PartNumber 800231-101
L7, L9: 0.67uH; TOROID_T50_VERT; PartNumber 800234-506
L8: 0.608uH; TOROID_T50_VERT; PartNumber 800234-506
R12: 12K; RC0805; PartNumber 800XXX-XXX

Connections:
/Sheet605F7A0C/ANT_RF: K7.6; also elsewhere on the board
/Sheet605F7A0C/Sheet605F8D0A/20_N1_RF: C37.1, C38.1, C39.1, K6.1, K6.12, L7.1
/Sheet605F7A0C/Sheet605F8D0A/20_N2_RF: C36.2, C40.1, C41.1, C42.1, L7.2, L8.1
/Sheet605F7A0C/Sheet605F8D0A/20_N3_RF: C36.1, C43.1, C44.1, C45.1, L8.2, L9.1
/Sheet605F7A0C/Sheet605F8D0A/20_N4_RF: C46.1, C47.1, C48.1, K7.1, K7.12, L9.2
/Sheet605F7A0C/TXRX_RF: K6.6; also elsewhere on the board
/Sheet605F7A0C/~SEL20: C110.1, C111.1, CR4.1 (A), DS3.2 (K), K6.8, K7.8; also elsewhere on the board
GND: C37.2, C38.2, C39.2, C40.2, C41.2, C42.2, C43.2, C44.2, C45.2, C46.2, C47.2, C48.2, C110.2, C111.2, K6.7, K7.7; also elsewhere on the board
unnamed: DS3.1 (A), R12.1
P12V0: CR4.3 (C), K6.5, K7.5, R12.2; also elsewhere on the board

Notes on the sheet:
20 AWG
WA6ZFT
10T
20M Low Pass Filter Section
T50-6
8 Band HF Low Pass Filter
10T

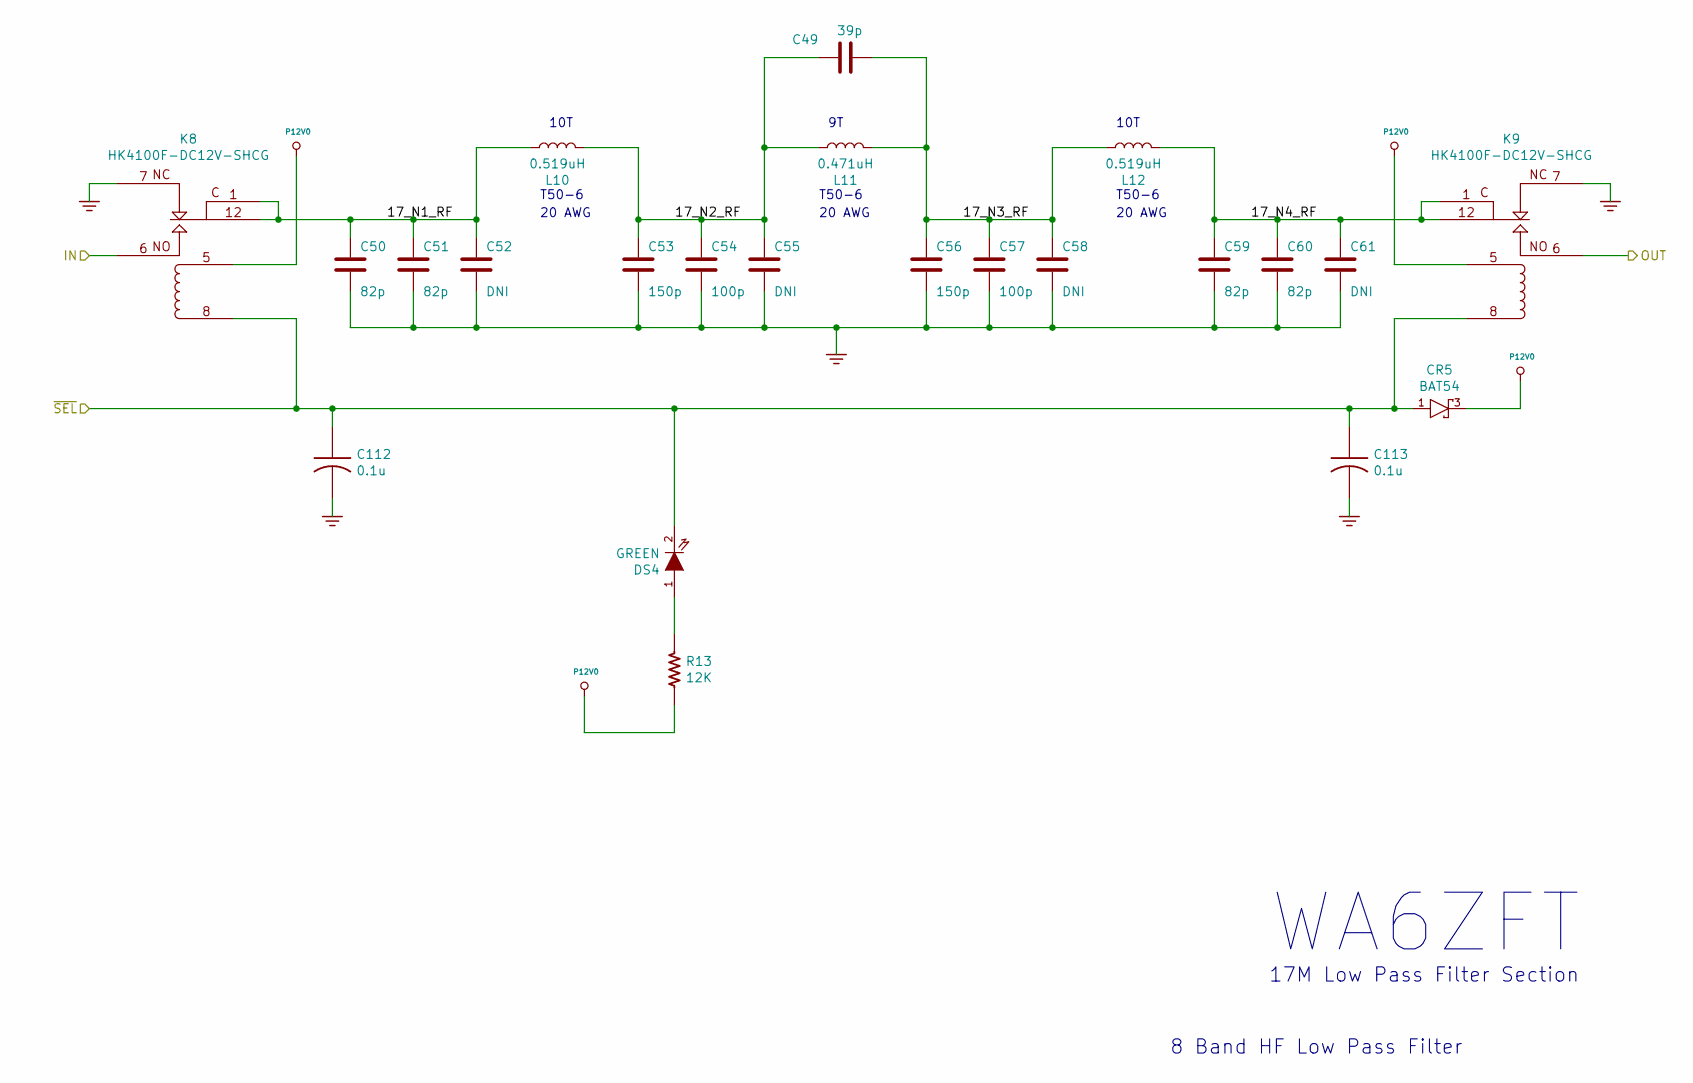
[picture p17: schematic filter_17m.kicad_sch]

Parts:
C49: 39p; CC0805; PartNumber 800232-390
C50, C51, C59, C60: 82p; CC0805; PartNumber 800232-820
C52, C55, C58, C61: DNI; CC0805; PartNumber 800XXX-XXX
C53, C56: 150p; CC0805; PartNumber 800232-151
C54, C57: 100p; CC0805; PartNumber 800232-101
C112, C113: 0.1u; CC0805; PartNumber 800063-XXX
CR5: BAT54; SOT23-3-SAR-V2; PartNumber 800127-101
DS4: GREEN; LED0805; PartNumber 800113-102
K8, K9: HK4100F-DC12V-SHCG; RELAY_HK4100; PartNumber 800231-101
L10, L12: 0.519uH; TOROID_T50_VERT; PartNumber 800234-506
L11: 0.471uH; TOROID_T50_VERT; PartNumber 800234-506
R13: 12K; RC0805; PartNumber 800XXX-XXX

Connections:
/Sheet605F7A0C/ANT_RF: K9.6; also elsewhere on the board
/Sheet605F7A0C/Sheet605F8D95/17_N1_RF: C50.1, C51.1, C52.1, K8.1, K8.12, L10.1
/Sheet605F7A0C/Sheet605F8D95/17_N2_RF: C49.2, C53.1, C54.1, C55.1, L10.2, L11.1
/Sheet605F7A0C/Sheet605F8D95/17_N3_RF: C49.1, C56.1, C57.1, C58.1, L11.2, L12.1
/Sheet605F7A0C/Sheet605F8D95/17_N4_RF: C59.1, C60.1, C61.1, K9.1, K9.12, L12.2
/Sheet605F7A0C/TXRX_RF: K8.6; also elsewhere on the board
/Sheet605F7A0C/~SEL17: C112.1, C113.1, CR5.1 (A), DS4.2 (K), K8.8, K9.8; also elsewhere on the board
GND: C50.2, C51.2, C52.2, C53.2, C54.2, C55.2, C56.2, C57.2, C58.2, C59.2, C60.2, C61.2, C112.2, C113.2, K8.7, K9.7; also elsewhere on the board
unnamed: DS4.1 (A), R13.1
P12V0: CR5.3 (C), K8.5, K9.5, R13.2; also elsewhere on the board

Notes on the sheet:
WA6ZFT
20 AWG
T50-6
17M Low Pass Filter Section
10T
10T
8 Band HF Low Pass Filter

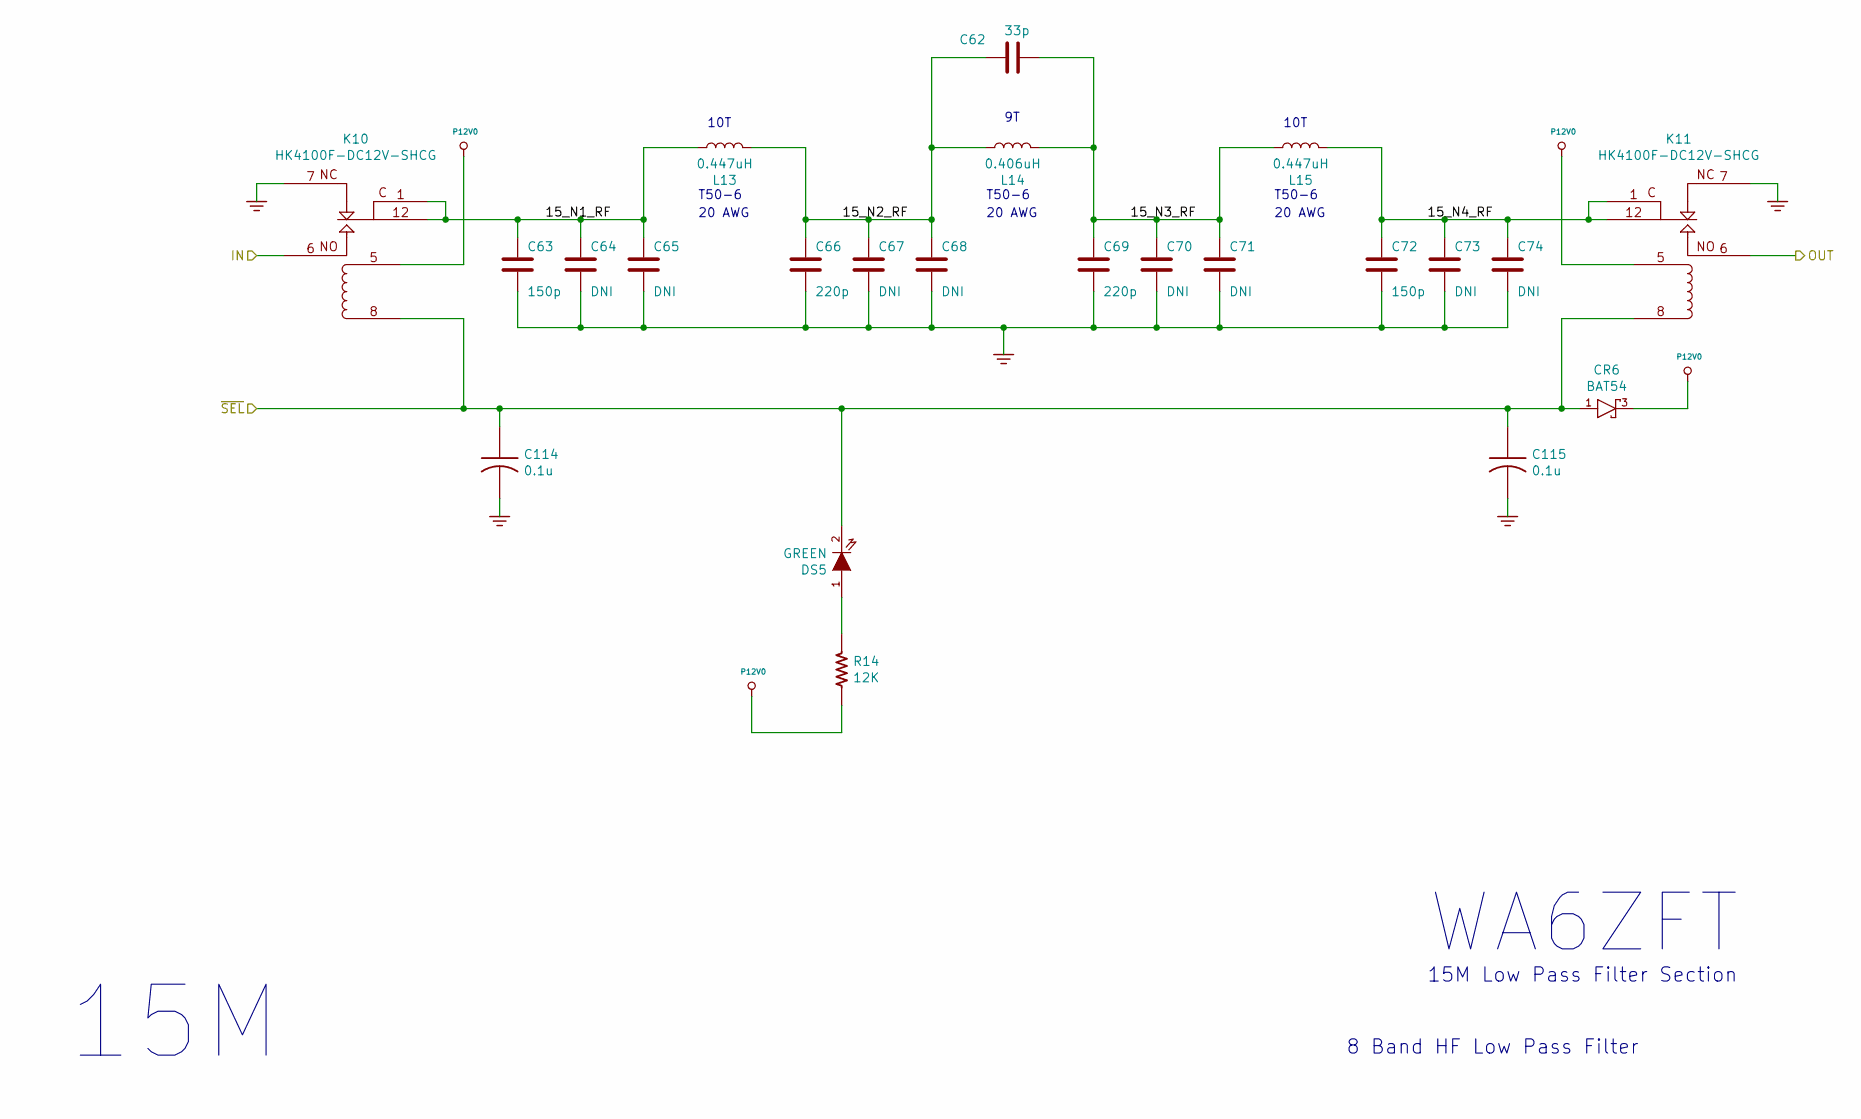
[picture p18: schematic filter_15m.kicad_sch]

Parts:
C62: 33p; CC0805; PartNumber 800232-330
C63, C72: 150p; CC0805; PartNumber 800232-151
C64, C65, C67, C68, C70, C71, C73, C74: DNI; CC0805; PartNumber 800XXX-XXX
C66, C69: 220p; CC0805; PartNumber 800232-221
C114, C115: 0.1u; CC0805; PartNumber 800063-XXX
CR6: BAT54; SOT23-3-SAR-V2; PartNumber 800127-101
DS5: GREEN; LED0805; PartNumber 800113-102
K10, K11: HK4100F-DC12V-SHCG; RELAY_HK4100; PartNumber 800231-101
L13, L15: 0.447uH; TOROID_T50_VERT; PartNumber 800234-506
L14: 0.406uH; TOROID_T50_VERT; PartNumber 800234-506
R14: 12K; RC0805; PartNumber 800XXX-XXX

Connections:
/Sheet605F7A0C/ANT_RF: K11.6; also elsewhere on the board
/Sheet605F7A0C/Sheet605F8DF5/15_N1_RF: C63.1, C64.1, C65.1, K10.1, K10.12, L13.1
/Sheet605F7A0C/Sheet605F8DF5/15_N2_RF: C62.2, C66.1, C67.1, C68.1, L13.2, L14.1
/Sheet605F7A0C/Sheet605F8DF5/15_N3_RF: C62.1, C69.1, C70.1, C71.1, L14.2, L15.1
/Sheet605F7A0C/Sheet605F8DF5/15_N4_RF: C72.1, C73.1, C74.1, K11.1, K11.12, L15.2
/Sheet605F7A0C/TXRX_RF: K10.6; also elsewhere on the board
/Sheet605F7A0C/~SEL15: C114.1, C115.1, CR6.1 (A), DS5.2 (K), K10.8, K11.8; also elsewhere on the board
GND: C63.2, C64.2, C65.2, C66.2, C67.2, C68.2, C69.2, C70.2, C71.2, C72.2, C73.2, C74.2, C114.2, C115.2, K10.7, K11.7; also elsewhere on the board
unnamed: DS5.1 (A), R14.1
P12V0: CR6.3 (C), K10.5, K11.5, R14.2; also elsewhere on the board

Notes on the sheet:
20 AWG
T50-6
10T
15M Low Pass Filter Section
15M
8 Band HF Low Pass Filter
10T
WA6ZFT

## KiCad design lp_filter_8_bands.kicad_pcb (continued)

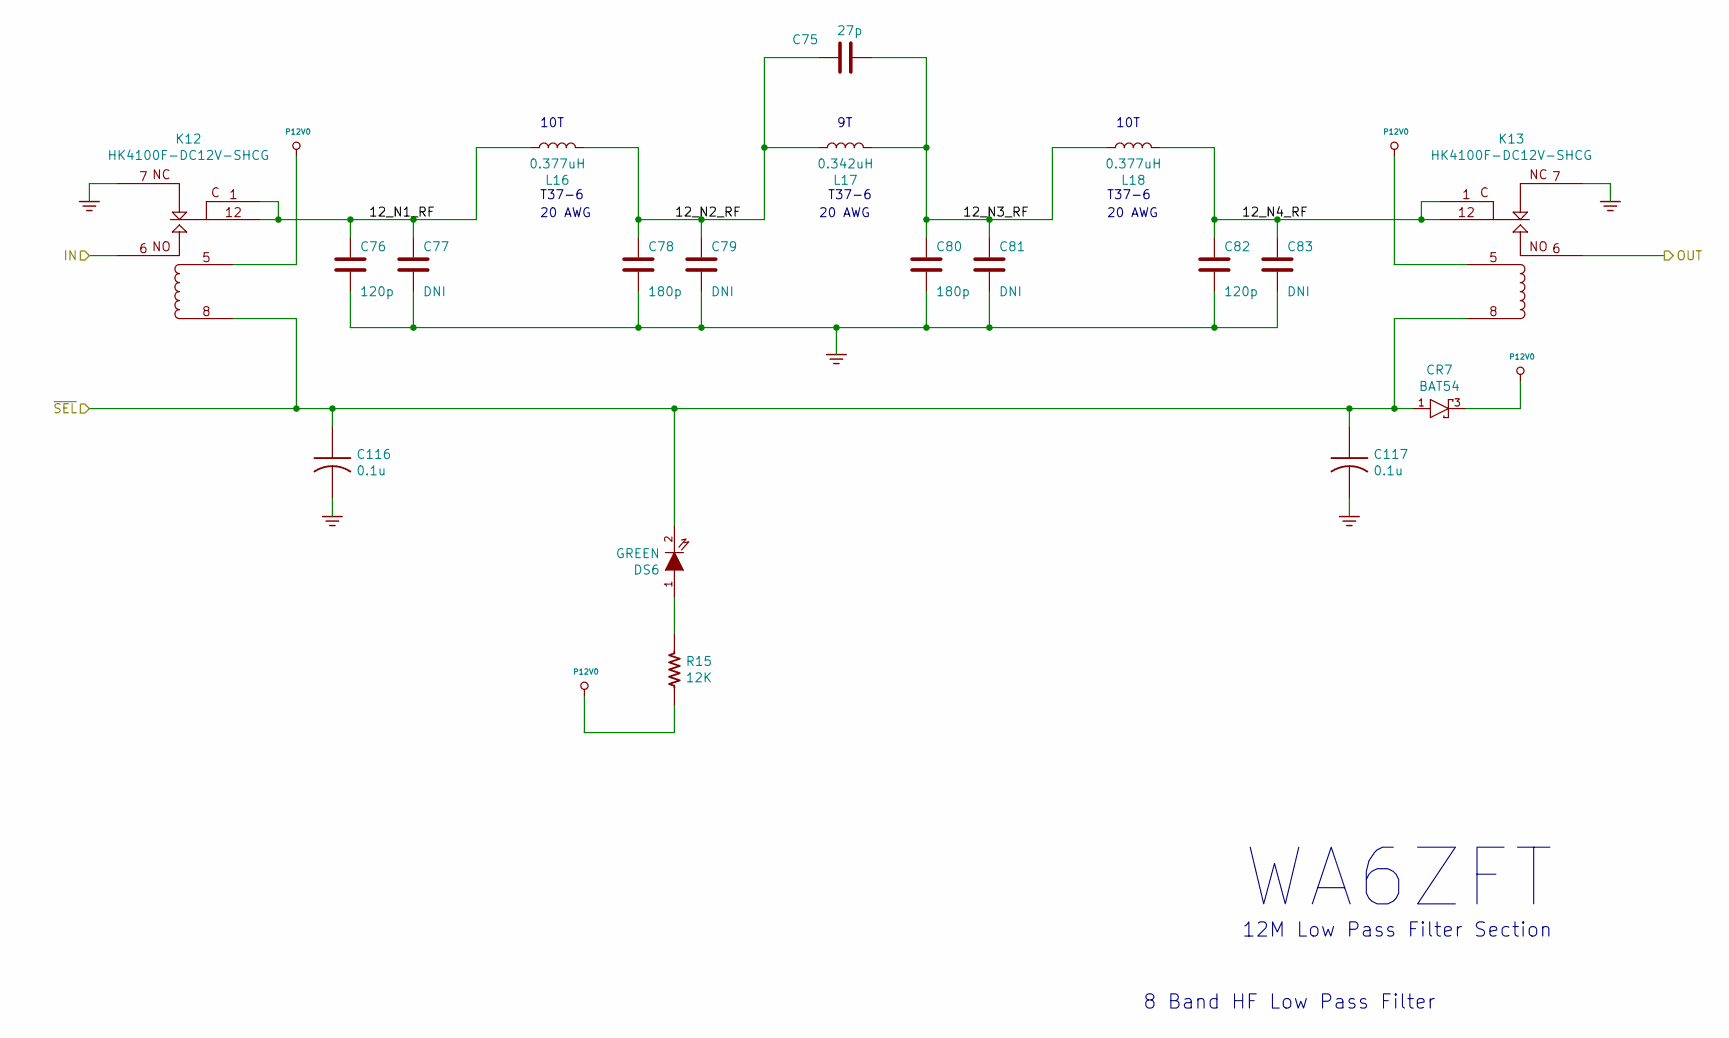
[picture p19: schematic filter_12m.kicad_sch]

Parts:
C75: 27p; CC0805; PartNumber 800232-270
C76, C82: 120p; CC0805; PartNumber 800232-121
C77, C79, C81, C83: DNI; CC0805; PartNumber 800XXX-XXX
C78, C80: 180p; CC0805; PartNumber 800232-181
C116, C117: 0.1u; CC0805; PartNumber 800063-XXX
CR7: BAT54; SOT23-3-SAR-V2; PartNumber 800127-101
DS6: GREEN; LED0805; PartNumber 800113-102
K12, K13: HK4100F-DC12V-SHCG; RELAY_HK4100; PartNumber 800231-101
L16, L18: 0.377uH; TOROID_T50_VERT; PartNumber 800234-506
L17: 0.342uH; TOROID_T50_VERT; PartNumber 800234-506
R15: 12K; RC0805; PartNumber 800XXX-XXX

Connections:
/Sheet605F7A0C/ANT_RF: K13.6; also elsewhere on the board
/Sheet605F7A0C/Sheet605F8E24/12_N1_RF: C76.1, C77.1, K12.1, K12.12, L16.1
/Sheet605F7A0C/Sheet605F8E24/12_N2_RF: C75.2, C78.1, C79.1, L16.2, L17.1
/Sheet605F7A0C/Sheet605F8E24/12_N3_RF: C75.1, C80.1, C81.1, L17.2, L18.1
/Sheet605F7A0C/Sheet605F8E24/12_N4_RF: C82.1, C83.1, K13.1, K13.12, L18.2
/Sheet605F7A0C/TXRX_RF: K12.6; also elsewhere on the board
/Sheet605F7A0C/~SEL12: C116.1, C117.1, CR7.1 (A), DS6.2 (K), K12.8, K13.8; also elsewhere on the board
GND: C76.2, C77.2, C78.2, C79.2, C80.2, C81.2, C82.2, C83.2, C116.2, C117.2, K12.7, K13.7; also elsewhere on the board
unnamed: DS6.1 (A), R15.1
P12V0: CR7.3 (C), K12.5, K13.5, R15.2; also elsewhere on the board

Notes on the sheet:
T37-6
8 Band HF Low Pass Filter
WA6ZFT
20 AWG
10T
12M Low Pass Filter Section
10T

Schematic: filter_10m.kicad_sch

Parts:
C84: 27p; CC0805; PartNumber 800232-270
C85, C91: 100p; CC0805; PartNumber 800232-101
C86, C92: DNI; CC0805; PartNumber 800XXX-XXX
C87, C88, C89, C90: 82p; CC0805; PartNumber 800232-820
C118, C119: 0.1u; CC0805; PartNumber 800063-XXX
CR8: BAT54; SOT23-3-SAR-V2; PartNumber 800127-101
DS7: GREEN; LED0805; PartNumber 800113-102
K14, K15: HK4100F-DC12V-SHCG; RELAY_HK4100; PartNumber 800231-101
L19, L21: 0.335uH; TOROID_T50_VERT; PartNumber 800234-506
L20: 0.304uH; TOROID_T50_VERT; PartNumber 800234-506
R16: 12K; RC0805; PartNumber 800XXX-XXX

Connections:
/Sheet605F7A0C/ANT_RF: K15.6; also elsewhere on the board
/Sheet605F7A0C/Sheet605F8E5D/10_N1_RF: C85.1, C86.1, K14.1, K14.12, L19.1
/Sheet605F7A0C/Sheet605F8E5D/10_N2_RF: C84.2, C87.1, C88.1, L19.2, L20.1
/Sheet605F7A0C/Sheet605F8E5D/10_N3_RF: C84.1, C89.1, C90.1, L20.2, L21.1
/Sheet605F7A0C/Sheet605F8E5D/10_N4_RF: C91.1, C92.1, K15.1, K15.12, L21.2
/Sheet605F7A0C/TXRX_RF: K14.6; also elsewhere on the board
/Sheet605F7A0C/~SEL10: C118.1, C119.1, CR8.1 (A), DS7.2 (K), K14.8, K15.8; also elsewhere on the board
GND: C85.2, C86.2, C87.2, C88.2, C89.2, C90.2, C91.2, C92.2, C118.2, C119.2, K14.7, K15.7; also elsewhere on the board
unnamed: DS7.1 (A), R16.1
P12V0: CR8.3 (C), K14.5, K15.5, R16.2; also elsewhere on the board

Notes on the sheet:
20 AWG
10T
WA6ZFT
T37-6
10M Low Pass Filter Section
8 Band HF Low Pass Filter

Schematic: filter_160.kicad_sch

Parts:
C93, C99, C102: 330p; CC0805; PartNumber 800232-331
C94: 47p; CC0805; PartNumber 800232-470
C95, C104: 1500p; CC0805; PartNumber 800232-152
C96, C105: 150p; CC0805; PartNumber 800232-151
C97, C100, C103, C106: DNI; CC0805; PartNumber 800XXX-XXX
C98, C101: 2200p; CC0805; PartNumber 800232-222
C120, C121: 0.1u; CC0805; PartNumber 800063-XXX
CR9: BAT54; SOT23-3-SAR-V2; PartNumber 800127-101
DS8: GREEN; LED0805; PartNumber 800113-102
K16, K17: HK4100F-DC12V-SHCG; RELAY_HK4100; PartNumber 800231-101
L22, L24: 5.21uH; TOROID_T80_VERT; PartNumber 800234-802
L23: 4.73uH; TOROID_T80_VERT; PartNumber 800234-802
R17: 12K; RC0805; PartNumber 800XXX-XXX

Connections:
/Sheet605F7A0C/ANT_RF: K17.6; also elsewhere on the board
/Sheet605F7A0C/Sheet605F91C6/160_N1_RF: C95.1, C96.1, C97.1, K16.1, K16.12, L22.1
/Sheet605F7A0C/Sheet605F91C6/160_N2_RF: C93.2, C94.2, C98.1, C99.1, C100.1, L22.2, L23.1
/Sheet605F7A0C/Sheet605F91C6/160_N3_RF: C93.1, C94.1, C101.1, C102.1, C103.1, L23.2, L24.1
/Sheet605F7A0C/Sheet605F91C6/160_N4_RF: C104.1, C105.1, C106.1, K17.1, K17.12, L24.2
/Sheet605F7A0C/TXRX_RF: K16.6; also elsewhere on the board
/Sheet605F7A0C/~SEL160: C120.1, C121.1, CR9.1 (A), DS8.2 (K), K16.8, K17.8; also elsewhere on the board
GND: C95.2, C96.2, C97.2, C98.2, C99.2, C100.2, C101.2, C102.2, C103.2, C104.2, C105.2, C106.2, C120.2, C121.2, K16.7, K17.7; also elsewhere on the board
unnamed: DS8.1 (A), R17.1
P12V0: CR9.3 (C), K16.5, K17.5, R17.2; also elsewhere on the board

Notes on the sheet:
29T
160M Low Pass Filter Section
T80-2
8 Band HF Low Pass Filter
22 AWG
31T
WA6ZFT

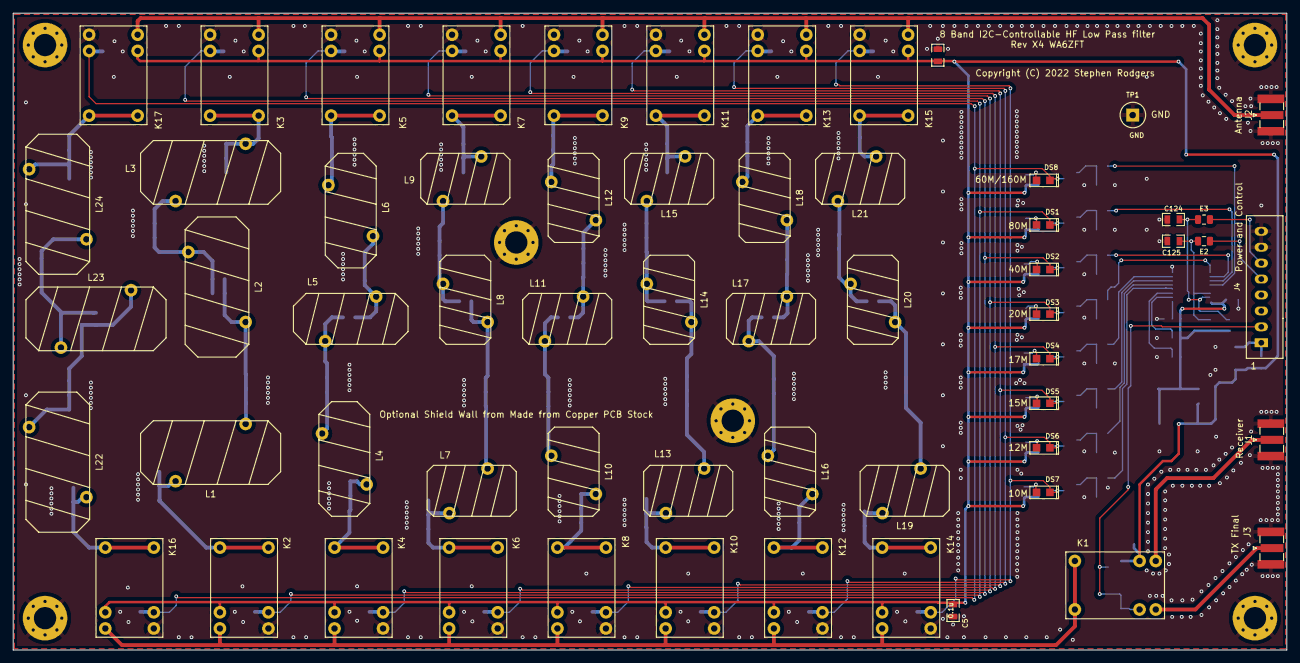
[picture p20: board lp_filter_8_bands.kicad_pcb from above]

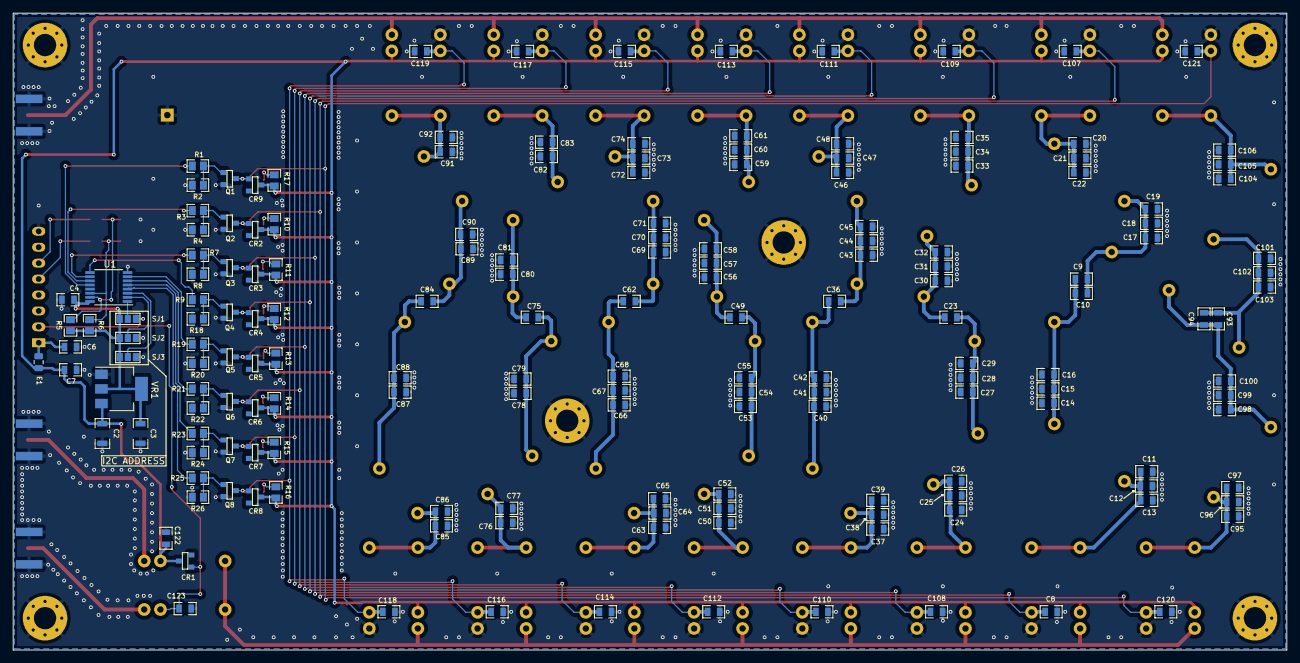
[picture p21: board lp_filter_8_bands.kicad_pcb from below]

Board: 2 copper layers, 200.0 x 100.0 mm, 236 parts (170 on the bottom side), 80 nets.

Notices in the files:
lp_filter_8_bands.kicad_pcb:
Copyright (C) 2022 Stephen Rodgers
